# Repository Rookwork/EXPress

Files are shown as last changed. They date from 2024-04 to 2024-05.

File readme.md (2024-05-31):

# EXPress

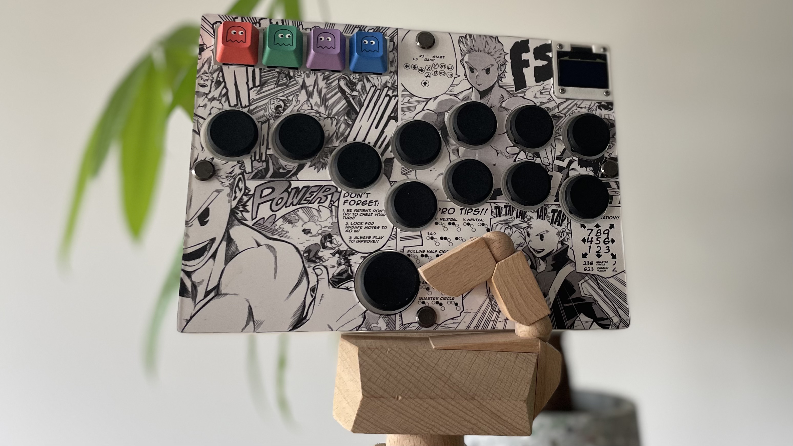
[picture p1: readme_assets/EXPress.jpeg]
The EXPress Controller


The EXPress (pronounced ee-ex-press, like EX moves) is a leverless DIY arcade controller with a focus on self expression.

**Features**
- Space for custom art on both the front and back
- Extra keys use MX switches with a slightly wider spacing to accommodate thicker artisan keycaps
- Main keys use Choc switches for faster inputs
- All switches are fully hot swappable
- Runs open-source GP2040-CE firmware for extremely low latency and fully remappable buttons 
- Includes an OLED screen to display layout and current mode

Custom art

Please note that I am providing these files free of charge with no promise of warranty or support. I try to explain the assembly process thoroughly, but it does still require some basic soldering skills and it is possible to mess up. Please take things slow, be careful, and try to enjoy the act of making something. :) 

I suggest reading through the entire guide at least once before deciding to order anything to make sure you understand each step and have the necessary tools. 

## Assembly guide

To assemble an EXPress, first we will need to order some parts. I will show the process using the exact vendors and process that I used, but there are many alternatives if you would like to shop around. The total cost of an EXPress should be around $150, give or take depending on how you get the parts made. 

Throughout this guide you will see expandable sections like this: 
<details>
<summary>"Click me to read more"</summary>
More information!
</details>

This guide is long, so various steps are hidden for readability. If you would like more detailed explanations of each step, just click the arrow to expand it and there will be more text and pictures.

### Ordering parts

We will need to order a few off the shelf parts:
- MCU: [Waveshare RP2040-Zero](RP2040-Zero) | [Amazon link](https://www.amazon.com/RP2040-Zero-High-Performance-Microcontroller-Castellated-Applications/dp/B09KZPCNPL)
- OLED Screen: [SSD1306 128x64px OLED Display](https://hosyond.com/#:~:text=0.96%20inch%20IIC%20OLED%20Module) | [Amazon link](https://www.amazon.com/gp/product/B09T6SJBV5/) | Note that there are lots of similar displays, but I can't guarantee they will fit. Many of these displays have similar measurements, but the tolerances are tight for this part, so I would try to get this exact screen if possible just to be on the safe side.
- 12 Choc v1 switches (whichever kind you want). I suggest a linear switch like Choc Reds, or an even lighter option like Pro Reds or Purpz. 
- 4 MX switches (whichever kind you want, but a 5-pin, PCB mount switch will be slightly more secure). Don't be afraid to try a fun switch you might not otherwise use — You don't hit these keys that often. I used Kailh Box White switches, for example. 
- 12 Choc v1 circular keycaps. I used ones from Junkfood Arcades, but you can also 3D print some, like those from [jfedor](https://github.com/jfedor2/flatbox/tree/master/3d-printed-buttoncaps) whose Flatbox design was a great inspiration to me. 
- 4 MX keycaps (whichever kind you want)
- 4 M5 15mm long Chicago screws | [Amazon link](https://www.amazon.com/gp/product/B09TT3TNPP) (set of several lengths)
- 10-16 M2 screws, 6-8mm long, and nuts | [Amazon link](https://www.amazon.com/gp/product/B0BD2CXW7D) (set of several lengths)

We will also need to get the following parts made:
- Three PCBs: the main body Choc switches mount, the MCU (microcontroller) mount, and the MX switches mount. These are three separate PCBs due to the different heights of these various parts. 
- The body of the case. We'll get this 3D printed. If you have your own 3D printer, you can probably make this yourself and save quite a bit of money.
- The top and bottom plates. We'll get these laser cut from acrylic. 
- Your own custom art

#### Ordering PCBs
<details>
<summary>"Ordering PCBs from JLPCB"</summary>
I used JLPCB for this. Upload each of the PCB zip files (one at a time). The only option you **must** change is the PCB thickness. This should be set to 1mm for each PCB. Do not forget!

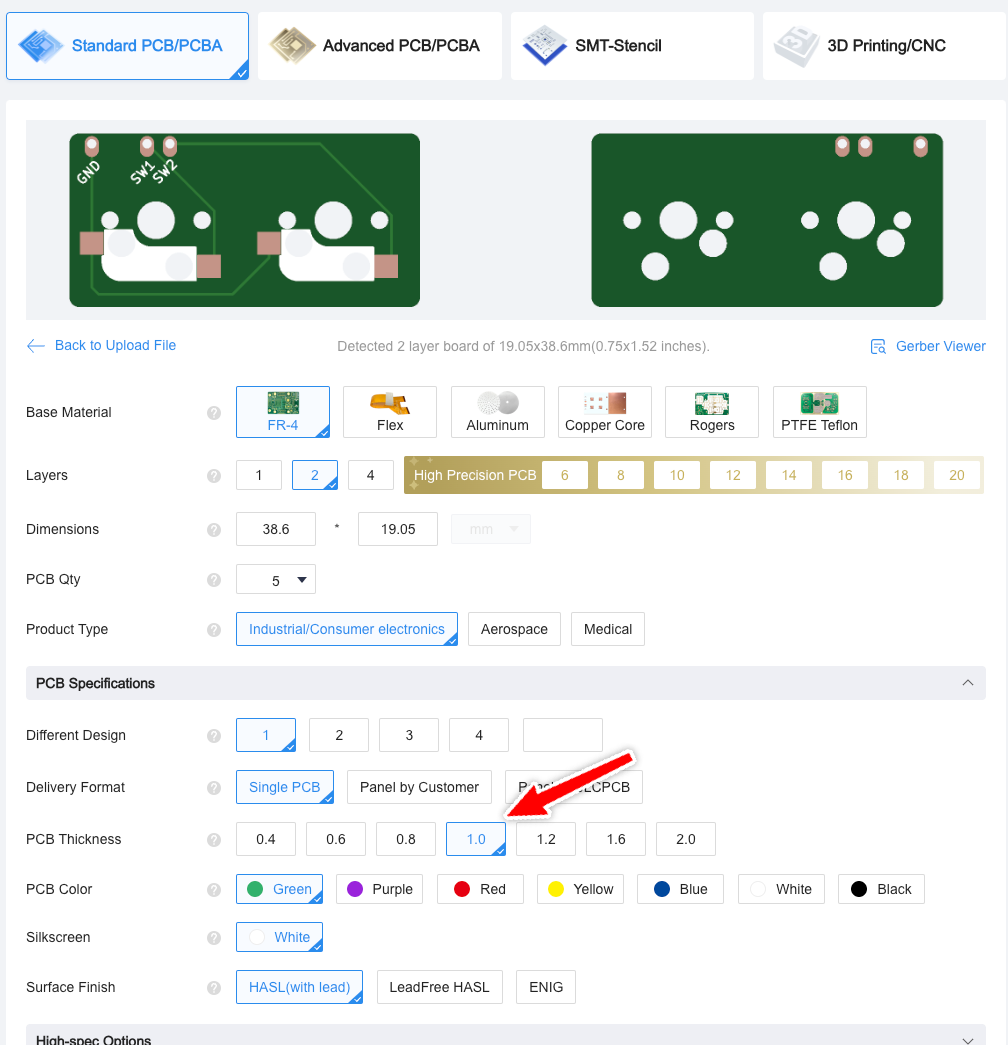
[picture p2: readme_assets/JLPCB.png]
PCB ordering


You can also change the color if you want, but these will be covered by art, so it's not really necessary.
</details>

#### Ordering body
<details>
<summary>"Ordering body from Shapeways"</summary>
I used Shapeways for this. Upload the body .stl file and double check the dimensions. It should be 199mm x 145mm. Then choose your material. I recommend SLA12, the cheapest option.

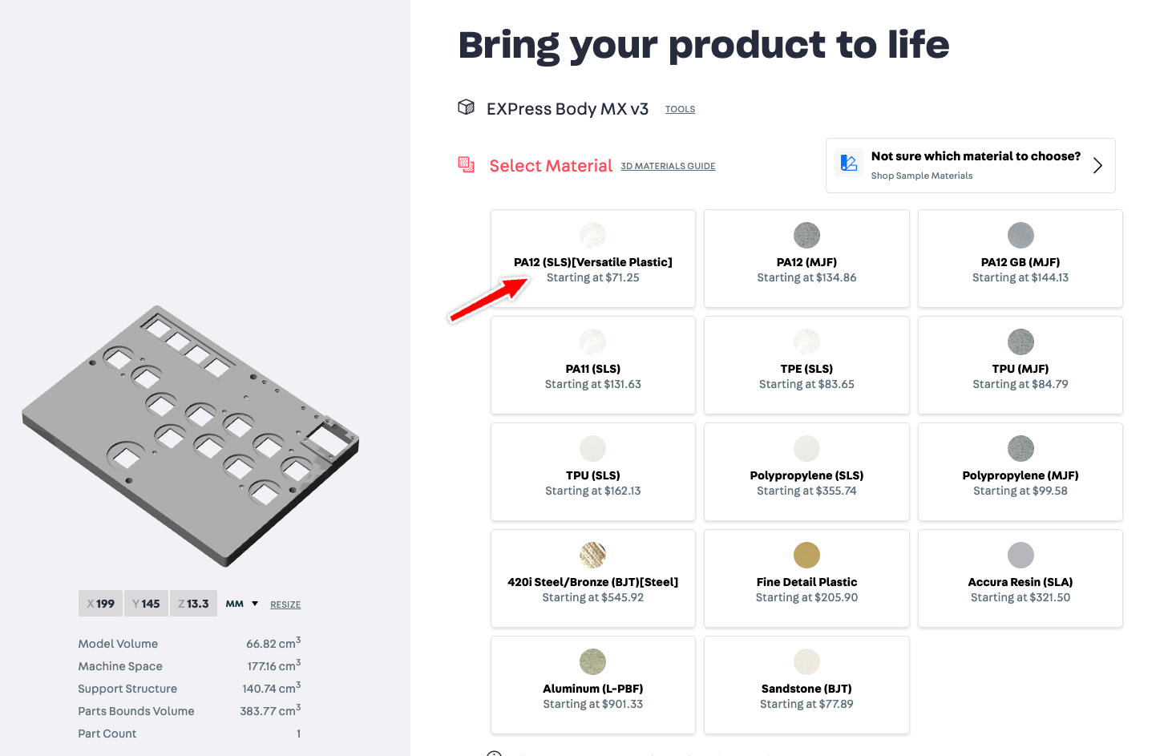
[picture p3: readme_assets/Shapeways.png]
Material


You can also change the color and finishing, but I have always used the default finishing option and have never had a complaint. The texture of the print will only be on the side of the case, you won't feel it, so it's not that important for it to be smooth.

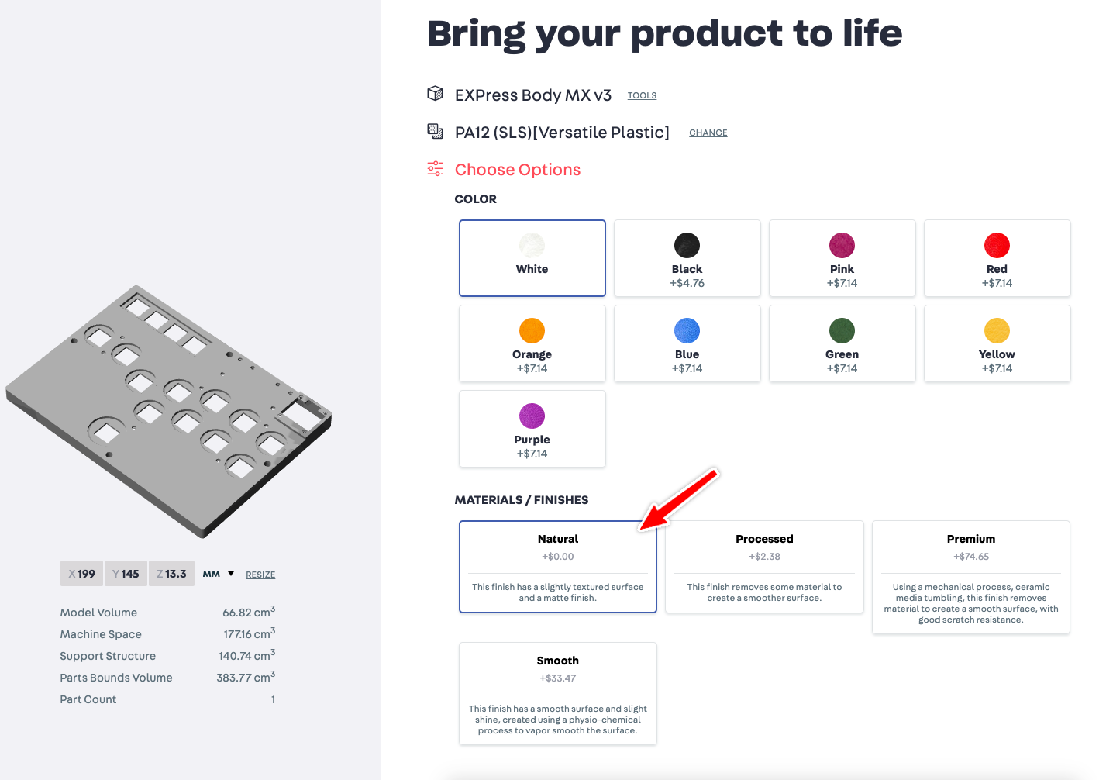
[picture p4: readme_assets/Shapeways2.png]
Color and finish

</details>

#### Ordering plates
<details>
<summary>"Ordering plates from Ponoko"</summary>
I used Ponoko for this. Upload the art plates .svg file. You may need to change the dimensions. 

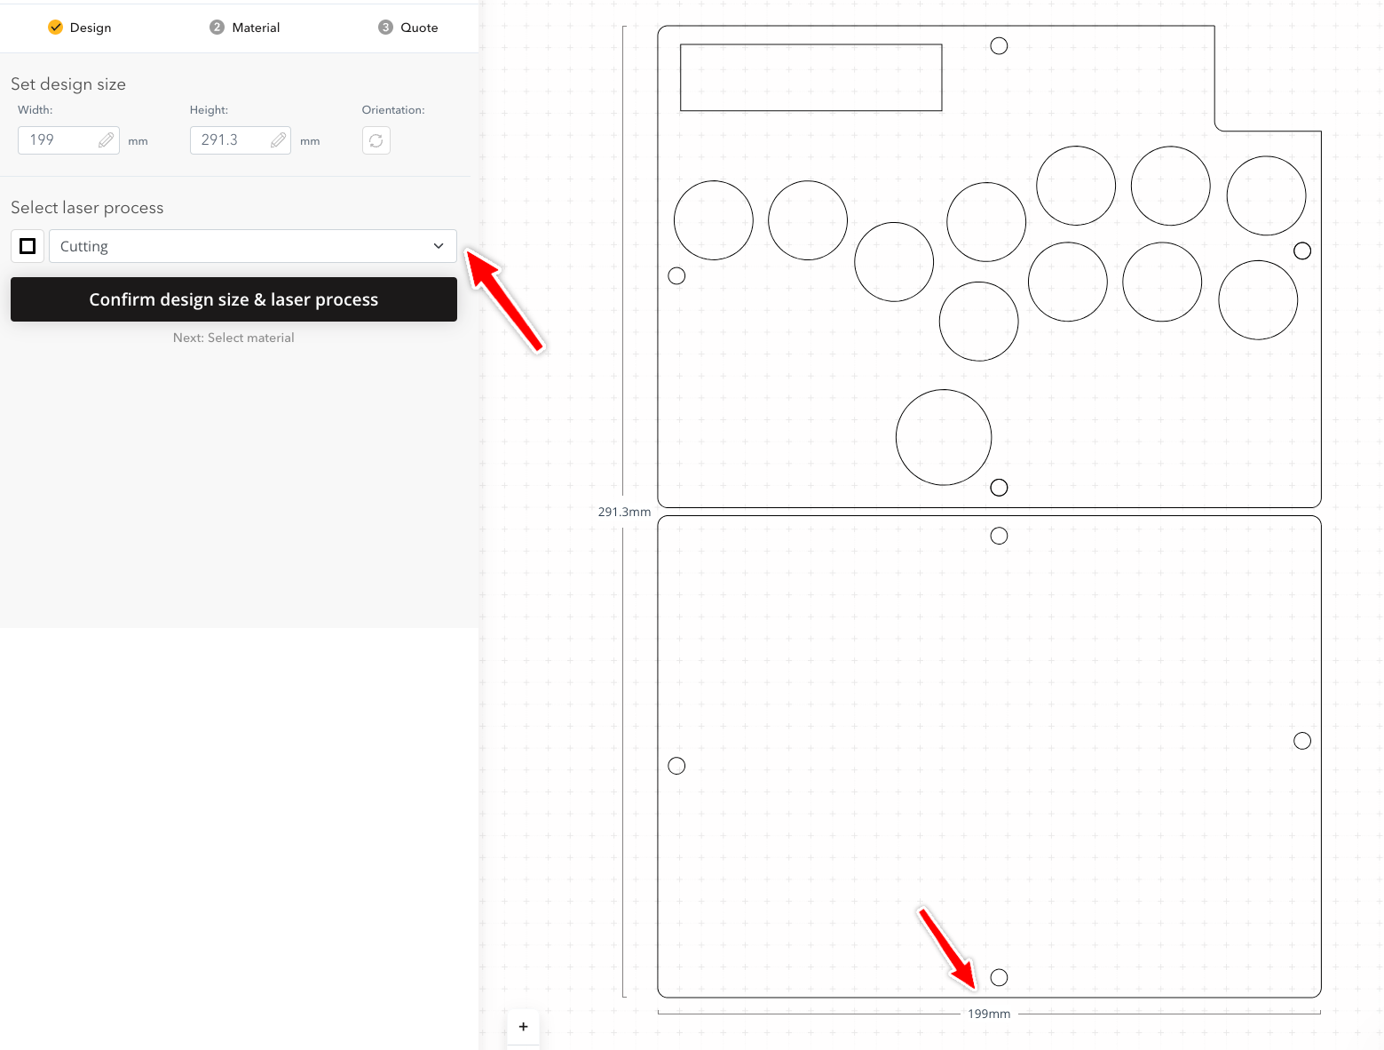
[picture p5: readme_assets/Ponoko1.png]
Ordering through Ponoko


Double-check that the width is 199mm specifically. Also, make sure the lines are set to "Cutting". 

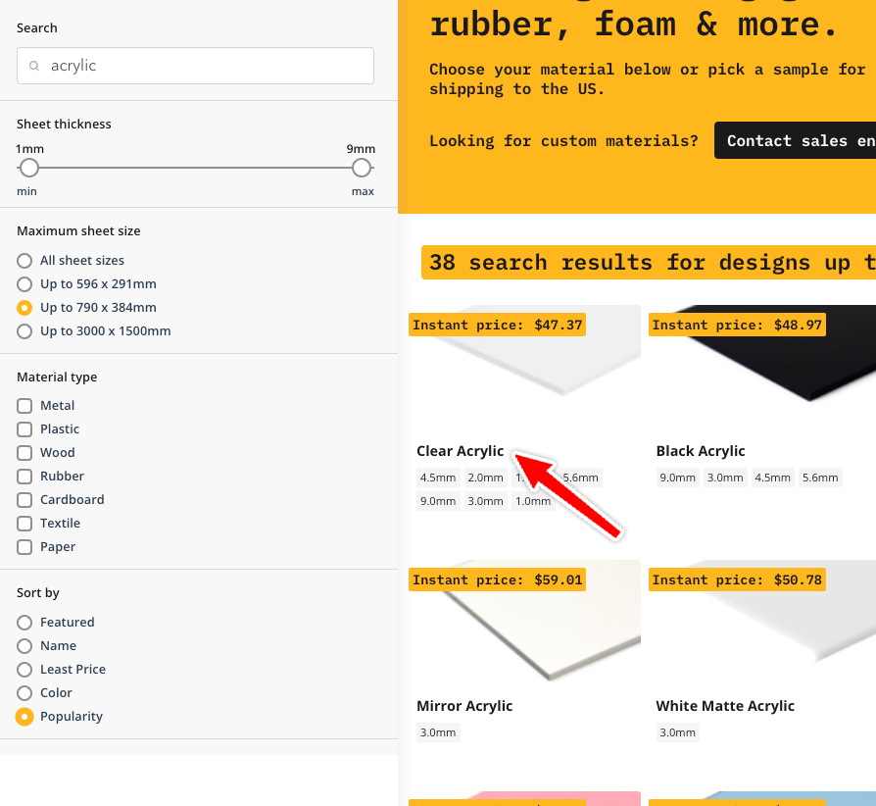
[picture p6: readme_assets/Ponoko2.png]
Ordering through Ponoko


Then, select your material. We want plain old clear acrylic. 

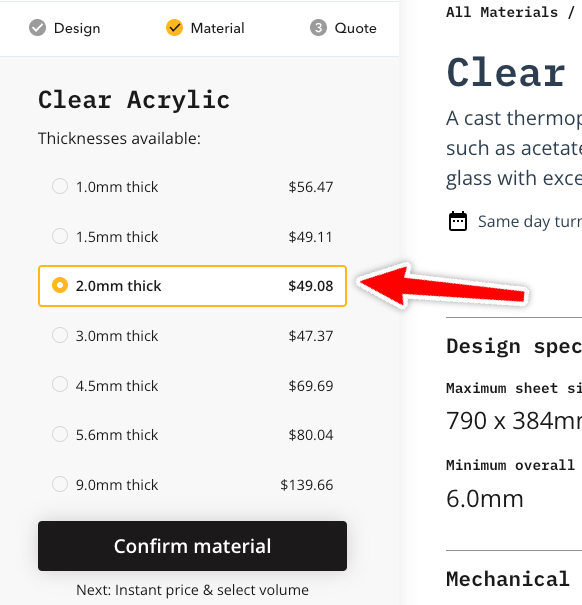
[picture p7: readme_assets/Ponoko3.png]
Ordering through Ponoko


Thenk select the thickness. **This is important.** Choose 2mm. 

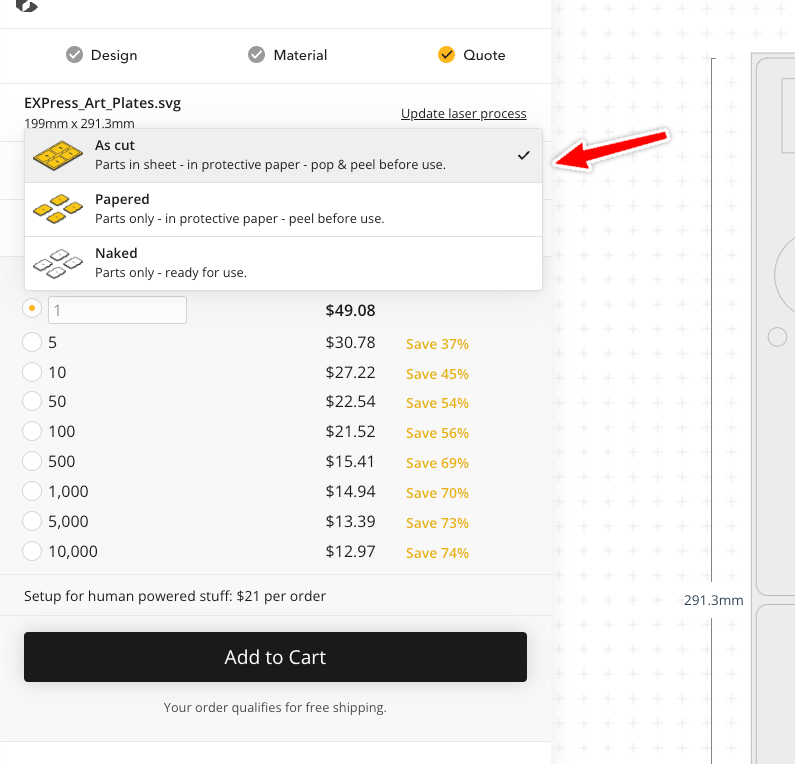
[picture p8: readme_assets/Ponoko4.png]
Ordering through Ponoko

You can also choose how you want the parts delivered. I like to leave it on "As cut". That means you'll get a big sheet in the mail and you pop the pieces out yourself. You can also choose "Papered" if you want a smaller package. I would not choose "Naked". It is far more expensive and not ideal for our purposes. We want the acrylic protected by the paper until we're ready to install it to avoid unnecessary smudges and scratches. 
</details>

#### Ordering custom art
<details>
<summary>"Ordering custom art through FedEx Office"</summary>
The art plates are designed to be printed on an A4 sheet of paper, but this is fairly hard to find in the US, so printing on an 11"x17" sheet with more whitespace around the design is also an option.

You can use the same .svg to help lay out your design. Note that the back plate screw holes are offset purposely — don't change them. This is necessary for the art to print correctly. 

I just used FedEx Kinko's copy service. If ordering online, choose "Copies" and a thicker paper for durability. 60lbs or 80lbs are both fine. Also, make sure you choose 11x17.

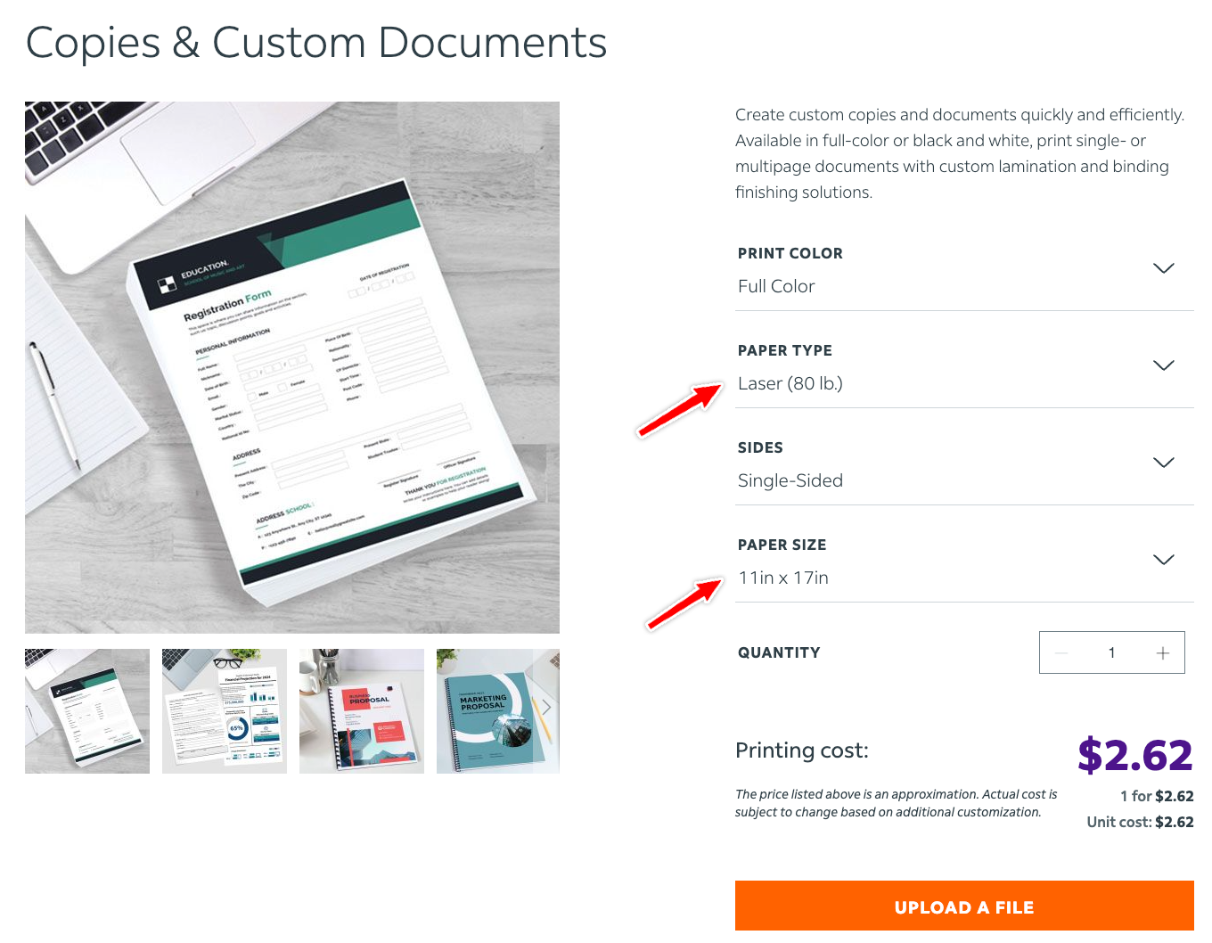
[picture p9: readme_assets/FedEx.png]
Ordering art


If you upload your file and FedEx asks you to resize it, stop, something is wrong. You should upload a file that is exactly 11x17 and FedEx shouldn't have any feedback about it. Resizing art through FedEx's tool makes this far more complicated. 

You could also check if a local print shop would do the job, but their willingness to do this will vary. This is an extremely small job for most shops, so it may not be worth the time to set it up. 
</details>

### Soldering and assembly

Before you begin soldering, there are a few other supplies you'll need
- Soldering iron and solder
- Some small gauge wire. I like 28 or 30 AWG. 

By the time you're reading this, I may have made some minor changes to the design of the PCBs, but the idea behind this process will be the same. If there are any major changes, I will note them. 

The overall idea here is we will complete the individual PCBS, put them in place, then connect them together. 

#### Test the MCU
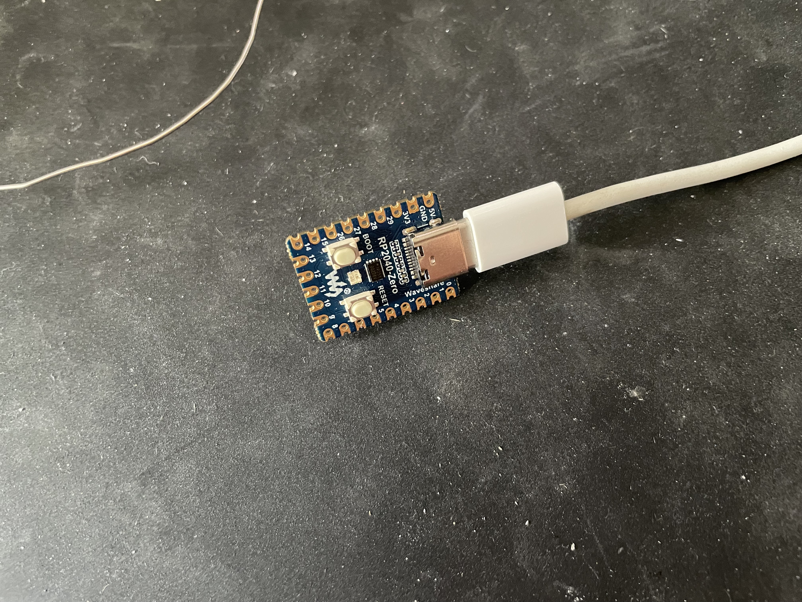
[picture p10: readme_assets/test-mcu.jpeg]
Test the MCU


<details>
<summary>"Testing the MCU"</summary>
Before you start anything else, it's a good idea to make sure your RP2040-Zero can flash the firmware. To do this, hold down the Boot button while plugging the board in. You should see it show up like a USB drive. Drag the firmware file into it and wait for it to disconnect. 

If you want to test the contacts of the MCU itself, you can bridge the ground pin to other contacts. You'll see buttons pressed on a tester like this: [https://hardwaretester.com/gamepad](https://hardwaretester.com/gamepad). You don't have to do this at this stage, though. As long as you can flash, things are probably on track.
</details>

#### OLED screen

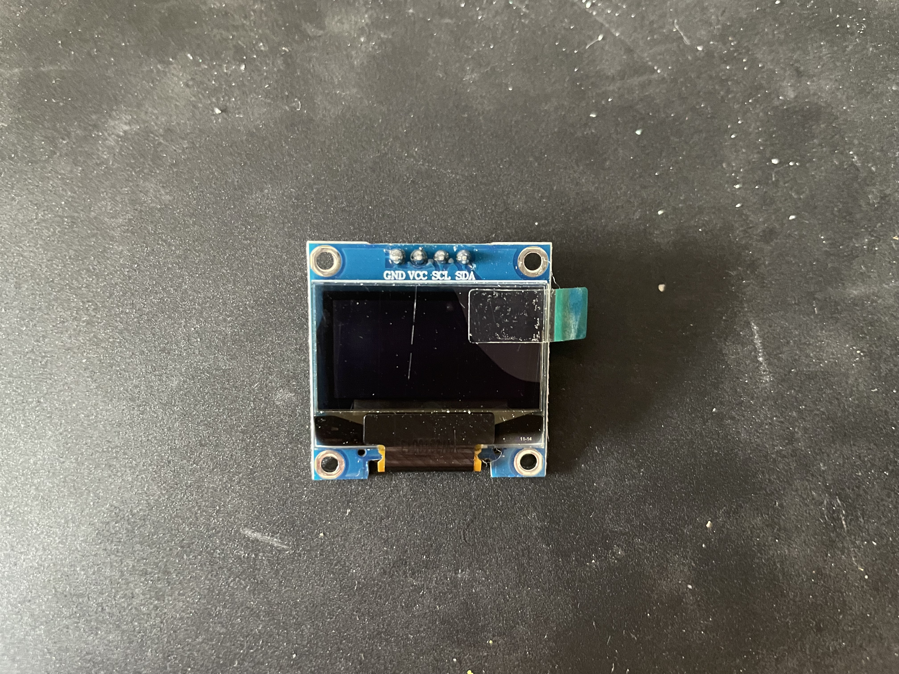
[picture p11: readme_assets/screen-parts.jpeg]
OLED screen


<details>
<summary>"Prepping the OLED screen"</summary>
There's not much we need to do with the screen besides trimming the existing pins if they come pre-soldered. You can leave the underside pins if you want, but you much trim the top pins down so the screen will fit flush. 

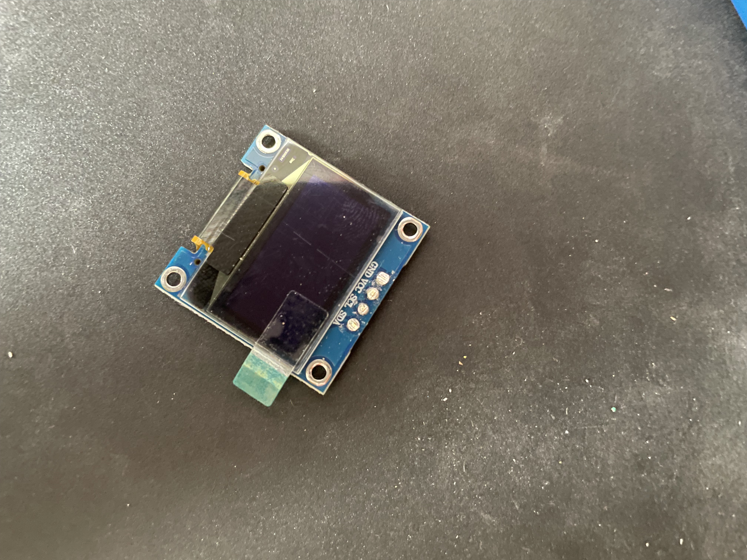
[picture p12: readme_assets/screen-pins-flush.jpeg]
Screen pins trimmed


Also, note the order of the pins and tin them.
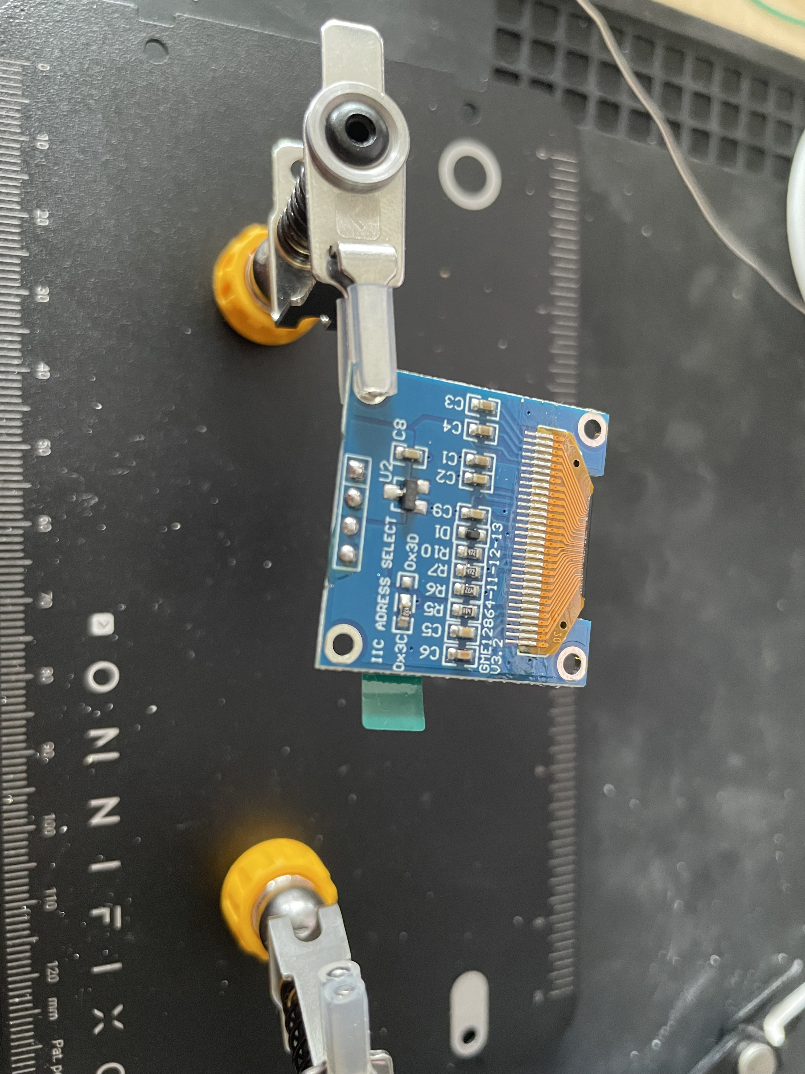
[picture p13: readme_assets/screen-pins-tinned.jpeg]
Screen pins tinned
 
</details>

#### MCU mount PCB

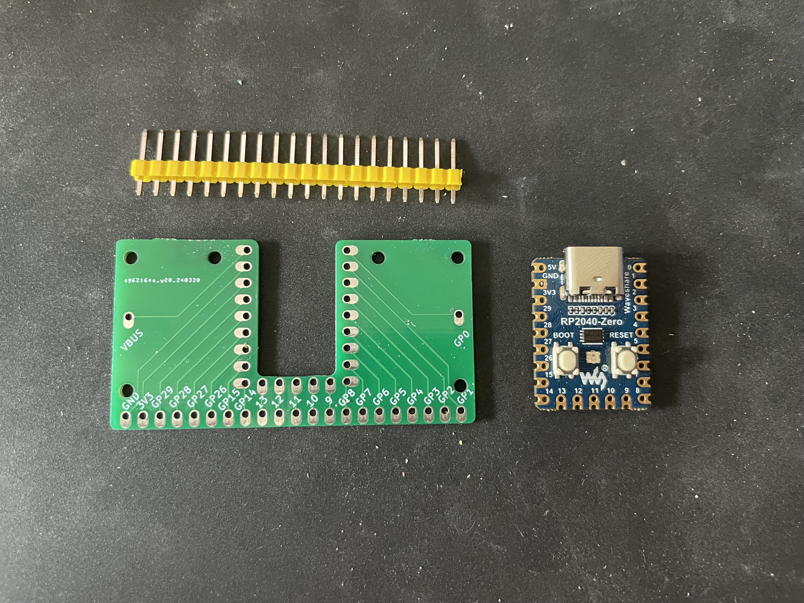
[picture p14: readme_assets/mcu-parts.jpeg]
MCU mount parts


<details>
<summary>"Preparing the MCU (microcontroller) mount"</summary>
To mount the RP2040-Zero, we need to attach it to the mounting PCB first. This will also make connecting the boards together a little more straightforward. 

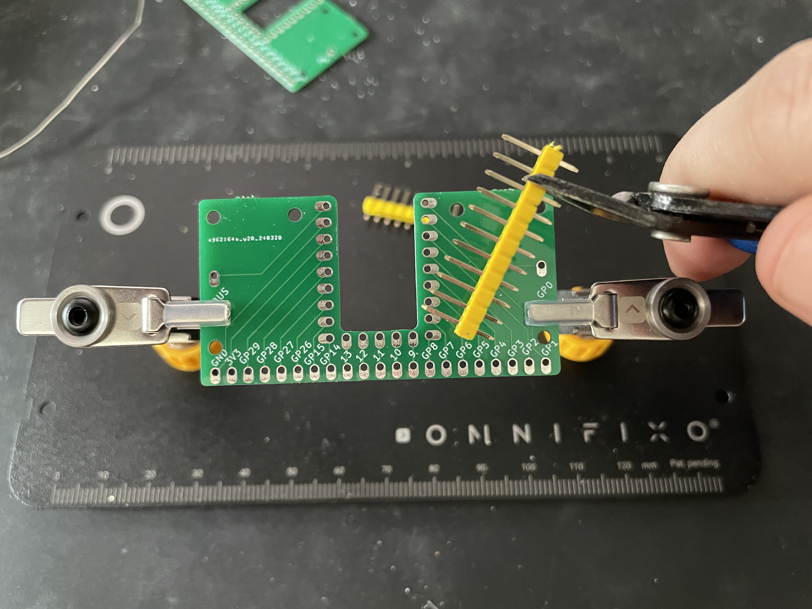
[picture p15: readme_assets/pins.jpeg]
Pins


There are a variety of ways you can mount the MCU. I recommend using a line of pins like this (it's okay if the line has too many pins — you can cut it to the right number), taping it to the back of the mount, and soldering the corners first so it stays in place. 

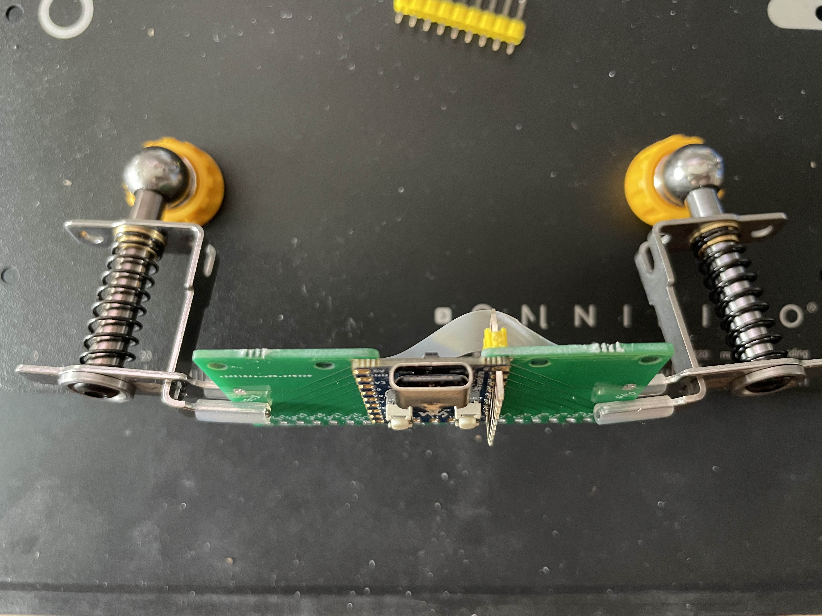
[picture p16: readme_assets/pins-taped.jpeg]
Pins taped on


It doesn't have to neat because we'll be trimming this in a moment. Finish soldering the line of pins. 

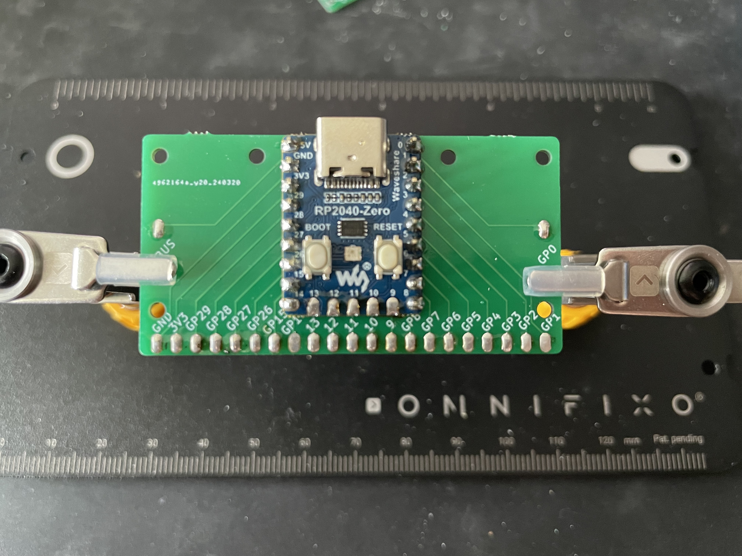
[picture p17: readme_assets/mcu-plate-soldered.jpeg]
MCU plate soldered


Then, work some snippers underneath the rubber sheathing and snip. Do this for all the pins so they are more or less flush (a little excess is okay.)

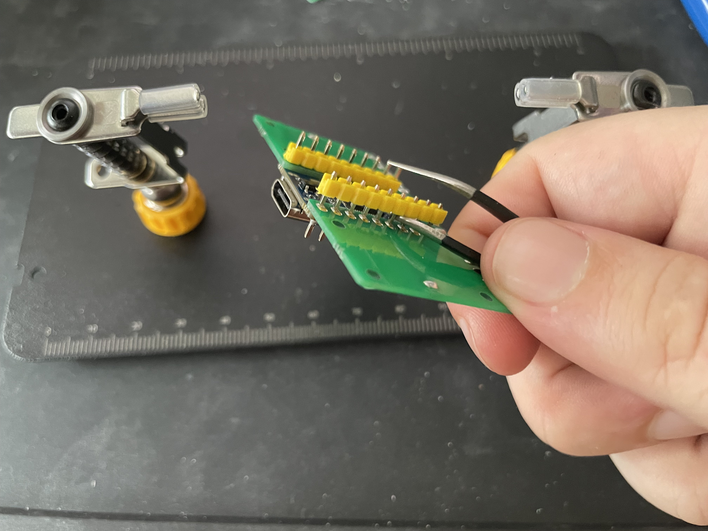
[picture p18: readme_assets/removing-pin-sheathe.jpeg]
Removing the sheathe from pins


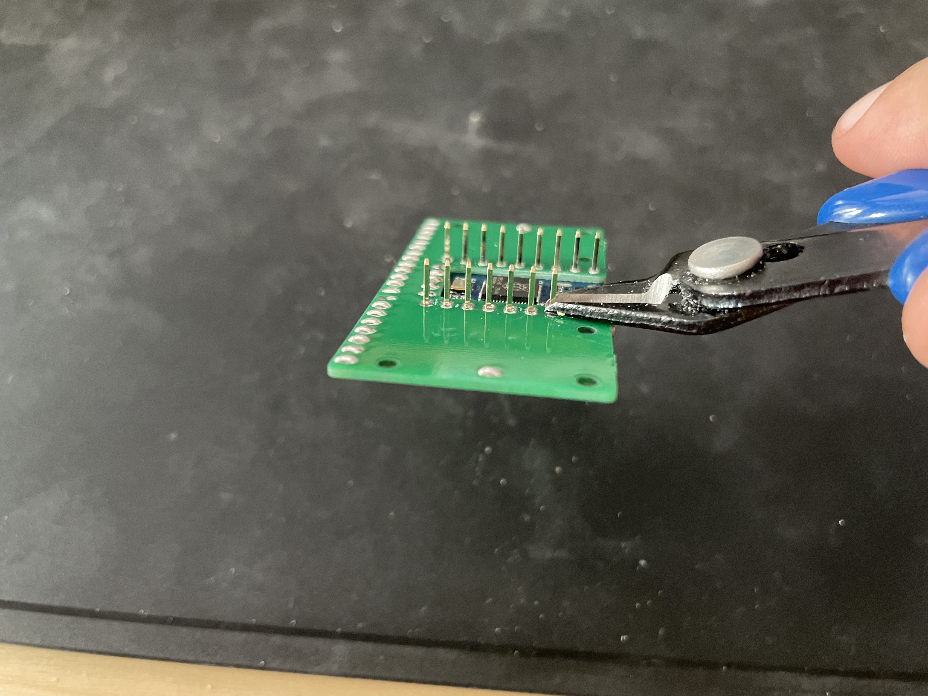
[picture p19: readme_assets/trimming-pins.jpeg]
Trimming the pins


Once the MCU is soldered on, it's also a good time to tin the other contacts with little mounds of solder on each one. 

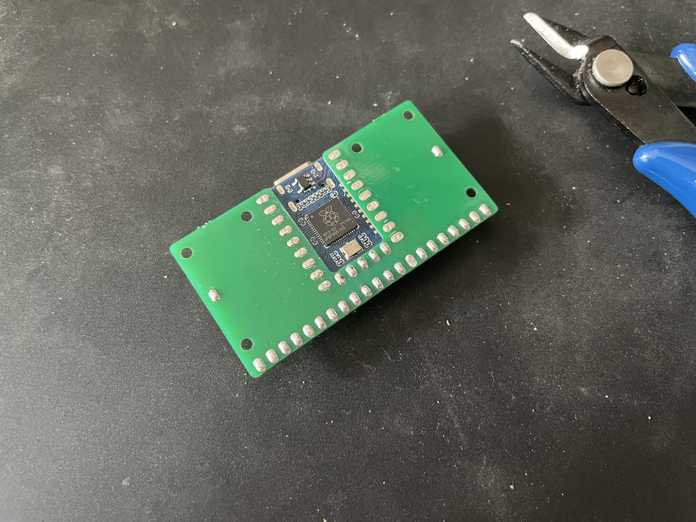
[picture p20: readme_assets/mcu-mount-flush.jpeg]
MCU mount trimmed flush

</details>

#### MX switch PCBs

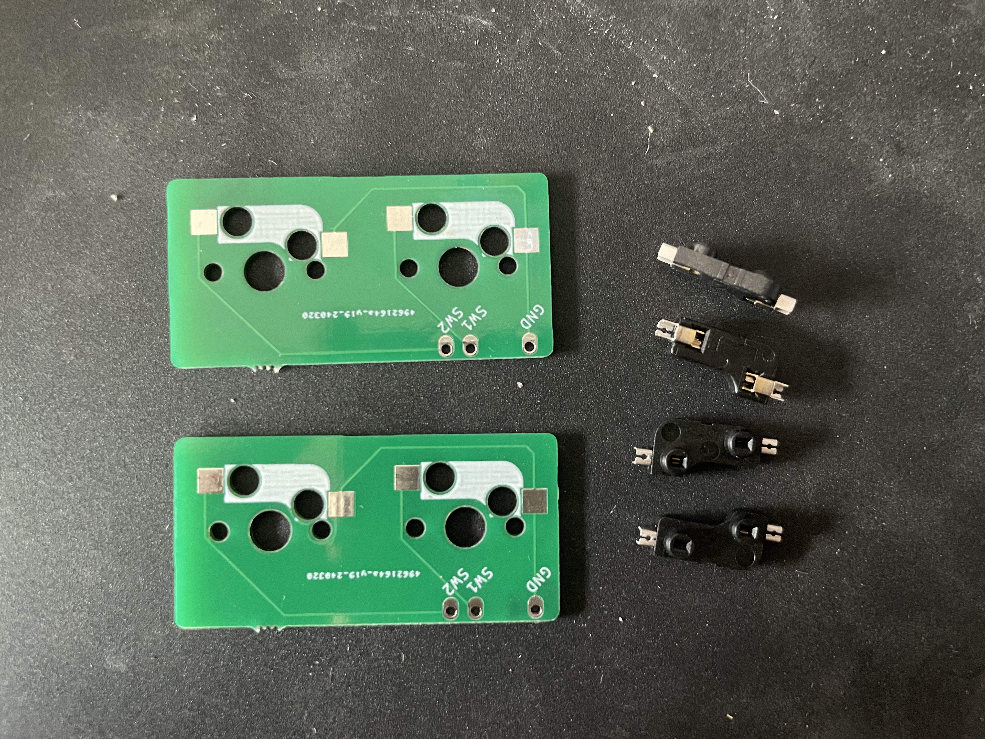
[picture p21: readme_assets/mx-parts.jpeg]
Preparing MX parts


<details>
<summary>"Preparing MX switch PCBs"</summary>
The MX plates are very straightforward. We just need to solder the hotswap sockets and tin the contacts. 

To solder the hotswap sockets, just hold the socket down and add solder to one side. Continue holding it for a second while the solder hardens to make sure it's flush. 
 
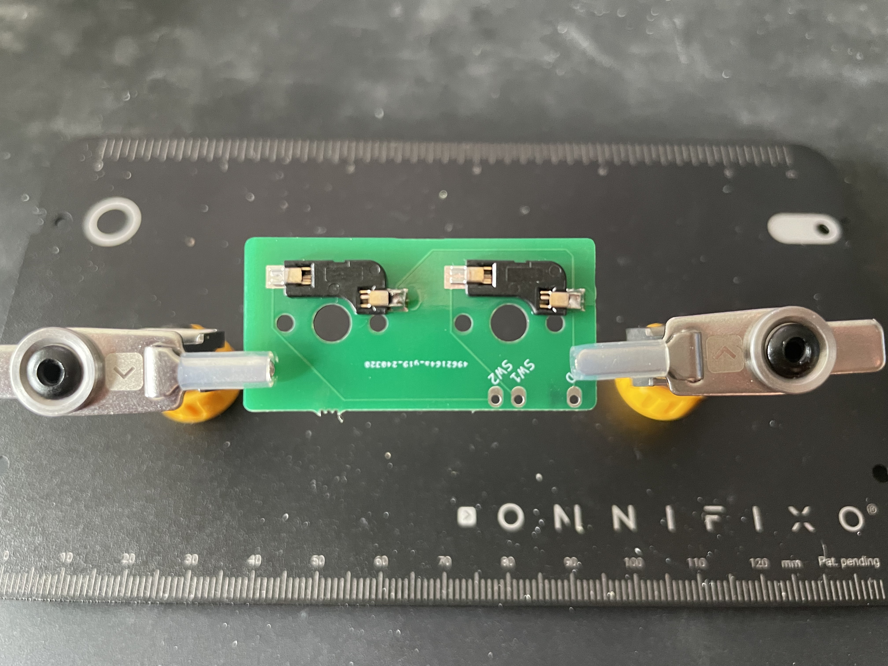
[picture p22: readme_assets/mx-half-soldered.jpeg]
One half of MX switch soldered


Then solder the other side and tin the contacts. 

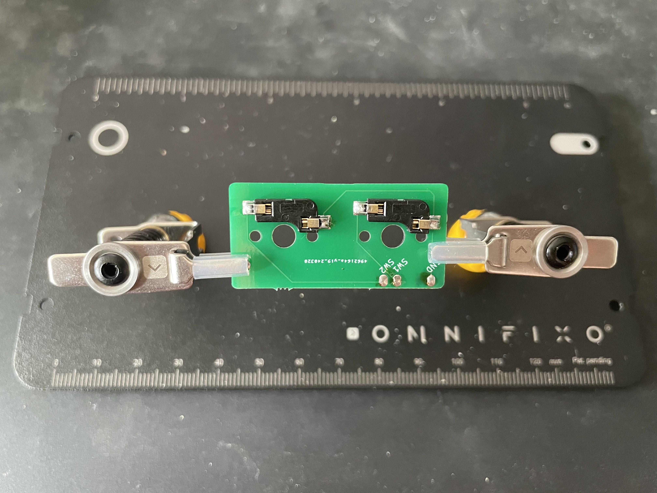
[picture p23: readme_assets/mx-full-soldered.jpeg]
MX switch mount soldered

</details>

#### Choc switch PCB

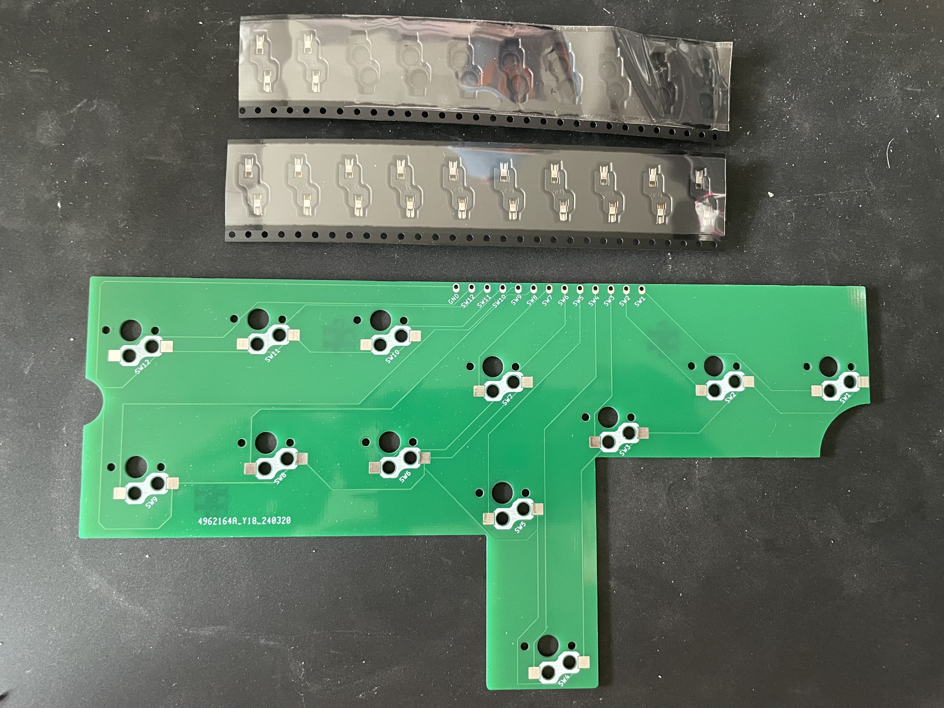
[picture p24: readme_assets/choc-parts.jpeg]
Choc switch parts


<details>
<summary>"Preparing the Choc switch PCB"</summary>
The Choc PCB is exactly the same as the MX ones. There are just more switches to solder. 

**Note the current Choc PCB is different from the one pictured. The process is still the same.**

Solder one side, then solder the other and repeat. Also, tin the contacts.

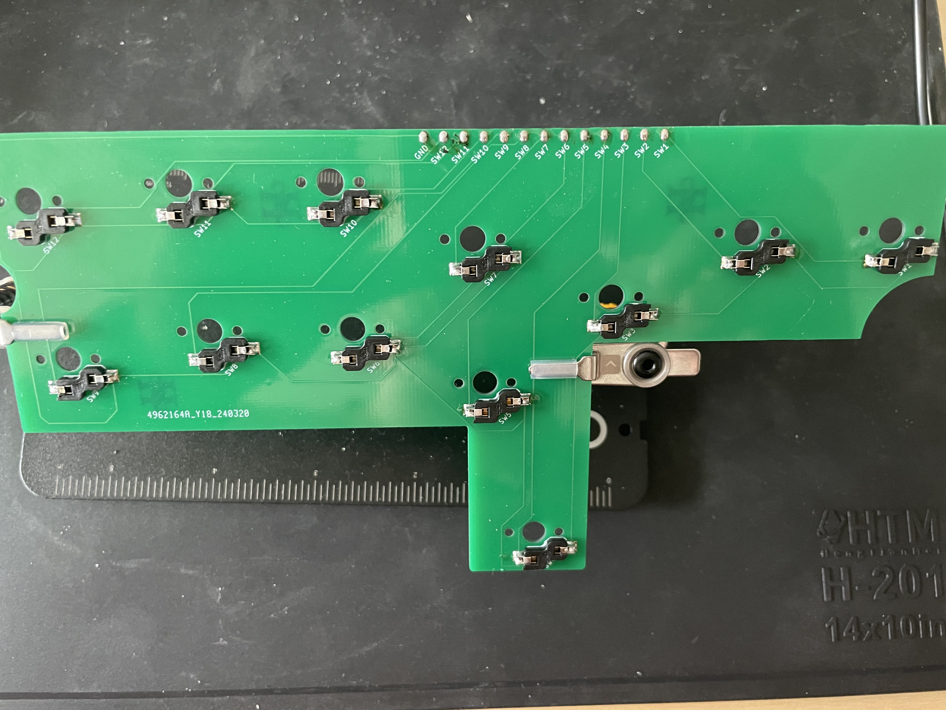
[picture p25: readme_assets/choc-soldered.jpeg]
Choc switches soldered


And tin the contacts above.
</details>

#### Installing the PCBs

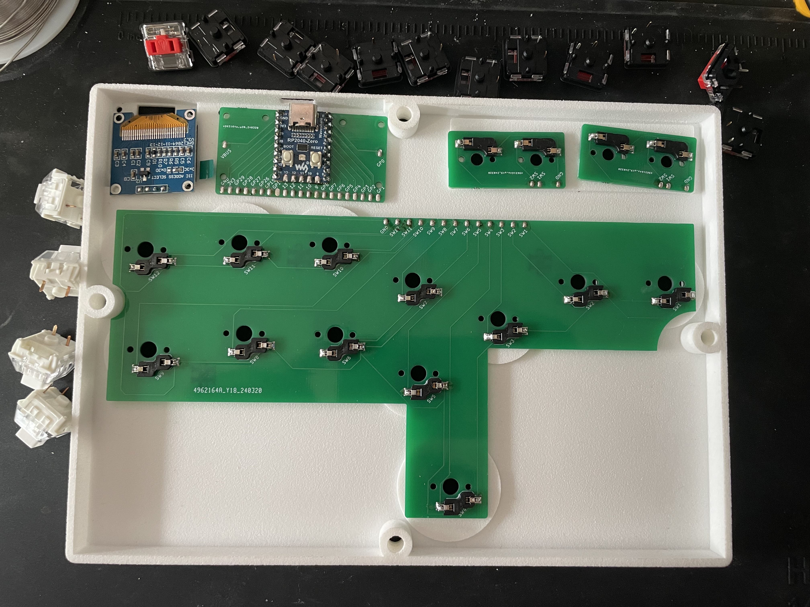
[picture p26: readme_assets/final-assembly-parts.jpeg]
Parts for final assembly


<details>
<summary>"Installing the PCBs in the body"</summary>
The OLED screen and the MCU mount will be held in with M2 screws. The MX and Choc PCBs are secure enough just from clipping the switches into them, but the Choc PCB includes optional M2 screw holes as well. You won't see them in the images below, but they are included in the latest versions of the body and PCB. 

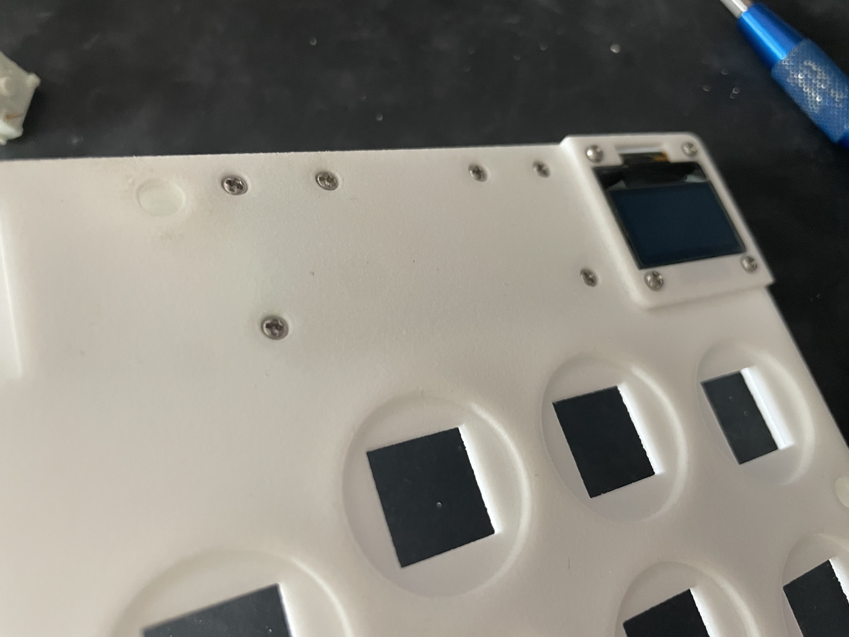
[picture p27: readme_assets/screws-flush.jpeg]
Screws flush


Screw in the OLED screen and MCU mount. The MCU screws are meant to sit flush in the body to be covered by the art. The OLED screw holes are a little tricky. Try to hold the nuts in place with tweezers and screw from the top. 

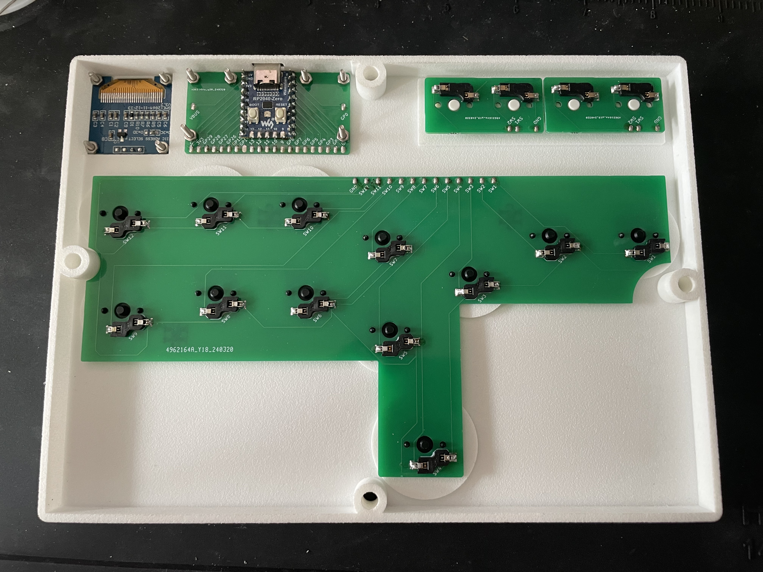
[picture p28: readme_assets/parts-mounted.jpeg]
All parts mounted


To install the switch mounts, clip the corner switches into the case first, then clip the PCBs onto the switches. When installing switches, **make sure to support the hotswap sockets from the back**. If you don't support the sockets, they may snap off. This is fixable, but it's annoying. 
</details>

#### Connecting them all together

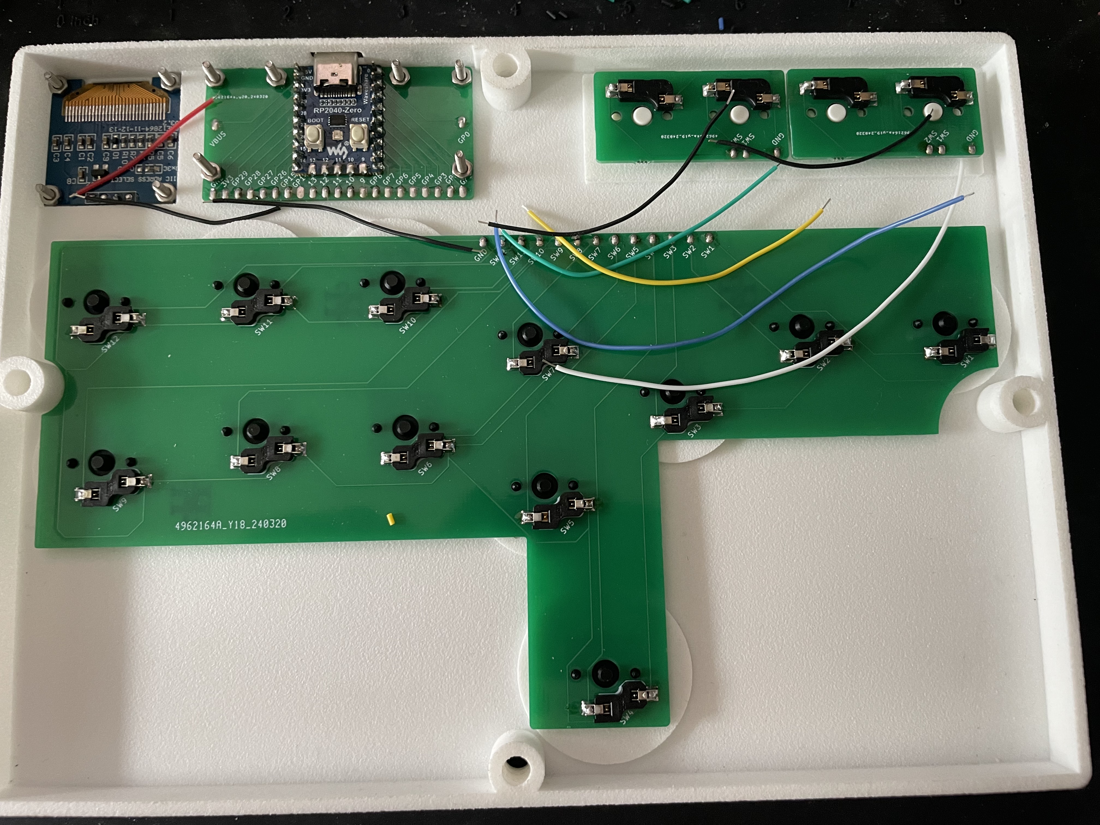
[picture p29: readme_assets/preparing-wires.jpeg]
Preparing the wiring


<details>
<summary>"PCB wiring guide"</summary>
Once everything is in position, it's time to break out the wire. Everything is in order. 

| Hardware pin | Switch # | GP2040 Button | Xbox Button |
| --- | --- | --- | --- |
| GP29 | - | - | - |
| GP28 | - | - | - |
| GP27 | - | OLED SCL | - |
| GP26 | - | OLED SDA | - |
| GP15 | 12 | L2 | LT |
| GP14 | 11 | L1 | LB |
| GP13 | 10 | R2 | RT |
| GP12 | 09 | R1 | RB |
| GP11 | 08 | B2 | B |
| GP10 | 07 | B4 | Y |
| GP09 | 06 | B1 | A |
| GP08 | 05 | B3 | X |
| GP07 | 04 | DPAD_Up | Up |
| GP06 | 03 | DPAD_Right | Right |
| GP05 | 02 | DPAD_Down | Down |
| GP04 | 01 | DPAD_Left | Left |
| GP03 | L_01 | L3 | LS |
| GP02 | R_02 | R3 | RS |
| GP01 | L_01 | S1 | Back |
| GP00 | L_02 | S2 | Start |

Simply heat up one contact, insert one end of the wire, and hold for a second. Then, repeat on the other side. 

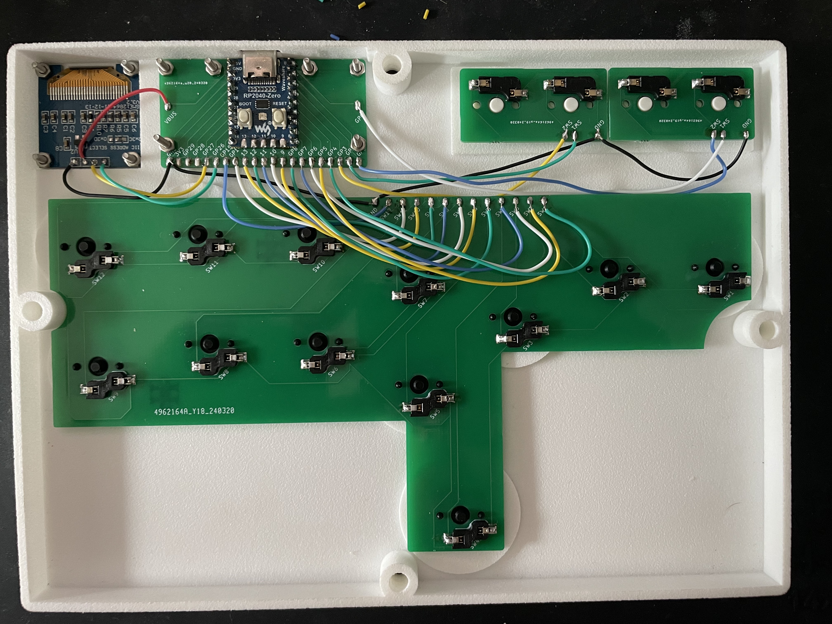
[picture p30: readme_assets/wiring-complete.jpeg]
Wiring complete

</details>

### Adding custom art
Please see [Cutting a Circle for Arcade Buttons](/cutting_arcade_stick_art/readme.md).

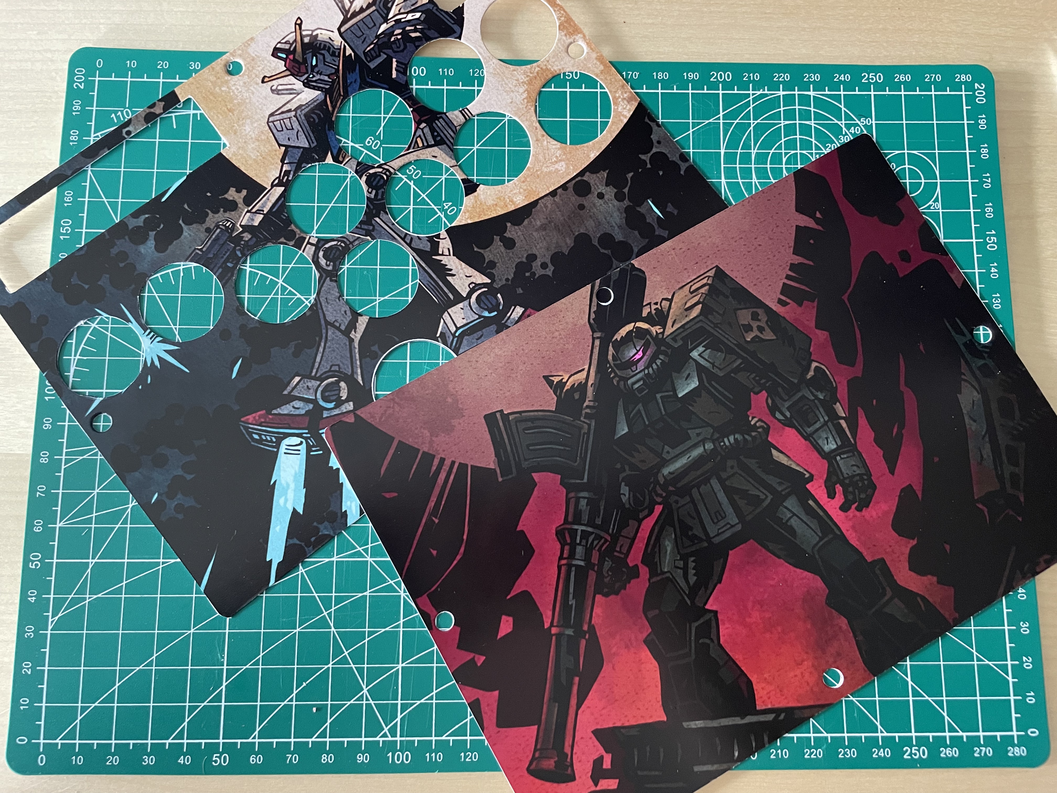
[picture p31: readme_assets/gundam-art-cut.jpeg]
Artwork cut out


The manga panels used for one set of art panels are from Boku No Hero Academia by Kōhei Horikoshi.
The Gundam art used for the other set of art panels are from [Chris Bourassa](https://twitter.com/bourassaart?lang=en). 

I made these art files for my personal use and will not be distributing them. 

### Flashing the firmware
If you flashed the firmware for testing earlier, the controller should now be working. If not, flash it now. 

To change any of the settings or pin mappings, you can use the great GP2040-CE web configurator: [https://gp2040-ce.info/web-configurator/](https://gp2040-ce.info/web-configurator/)

### Final assembly
With everything working, all that's left to do is remove the paper from the acrylic plates, put the art down, put the plates down, and screw everything together. While you do this, try to be careful not to touch the underside of the acrylic (the side that will touch the art). That way, any smudges that develop will be on the top faces and easy to clean. 

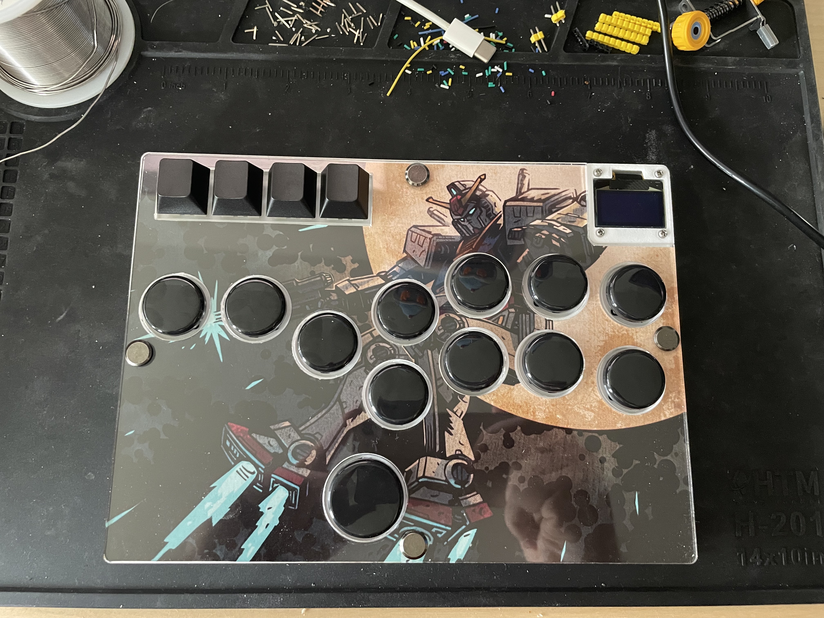
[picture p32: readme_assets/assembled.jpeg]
Two assembled EXPress controllers


Enjoy your EXPress! 

---

If you found this guide helpful, tips are always appreciated but never required.

<a href="https://www.buymeacoffee.com/rookwork" target="_blank">Buy Me A Coffee</a>

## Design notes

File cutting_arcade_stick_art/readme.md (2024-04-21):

# Cutting Custom Arcade Stick Art

When I first started working on [the EXPress](/readme.md), I had lots of worries about parts that would be difficult. Little did I know that one of the most difficult parts of this project would be something that never even occured to me to worry about: cutting circles. 

With traditional arcade buttons, you have little lips that cover any rough cuts, but with Choc switches, you don't have that luxury. Your cuts will be on full display, so they need to look good. 

I tested several methods and finally landed on one that produced good results. Here, I'll share my findings and tips. Not to spoil the surprise too much, but I only really recommend methods 1 and 4. 

## Method 1: Freehand with a standard hobby knife

You will want a hobby knife for this project anyway, so this is the cheaper approach with what you already have on hand. The results won't be as pretty, but if you're patient, you can still get decent looking cuts, especially at a distance. 

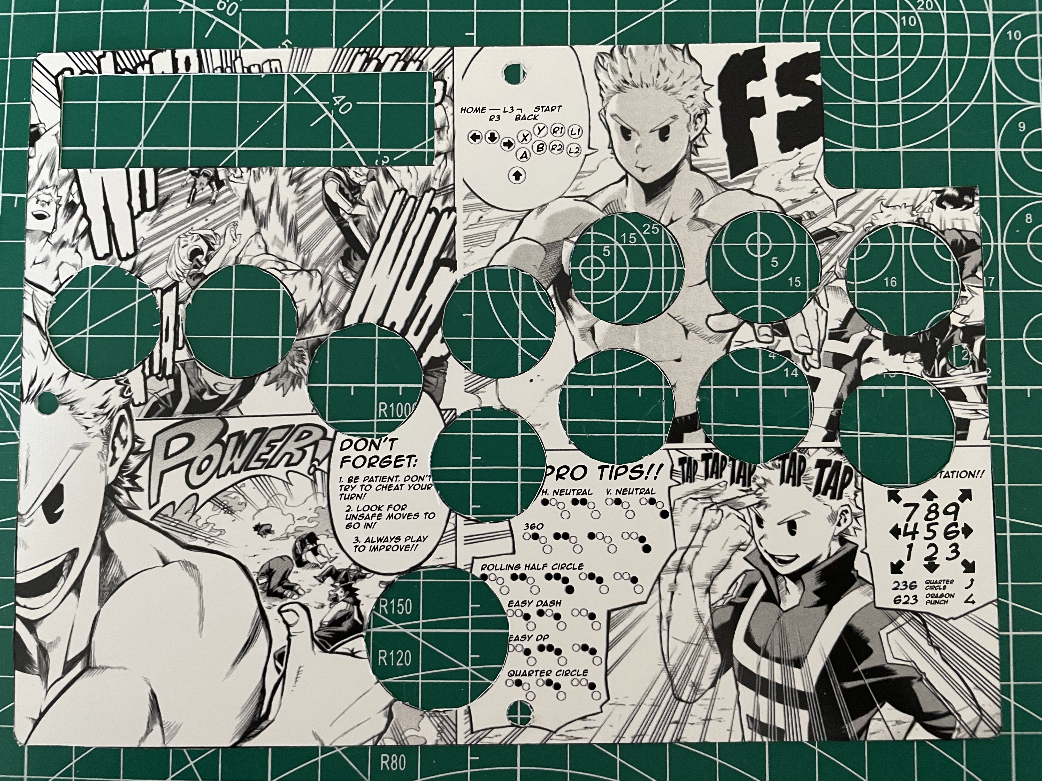
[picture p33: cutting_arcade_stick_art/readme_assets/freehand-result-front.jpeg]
Front

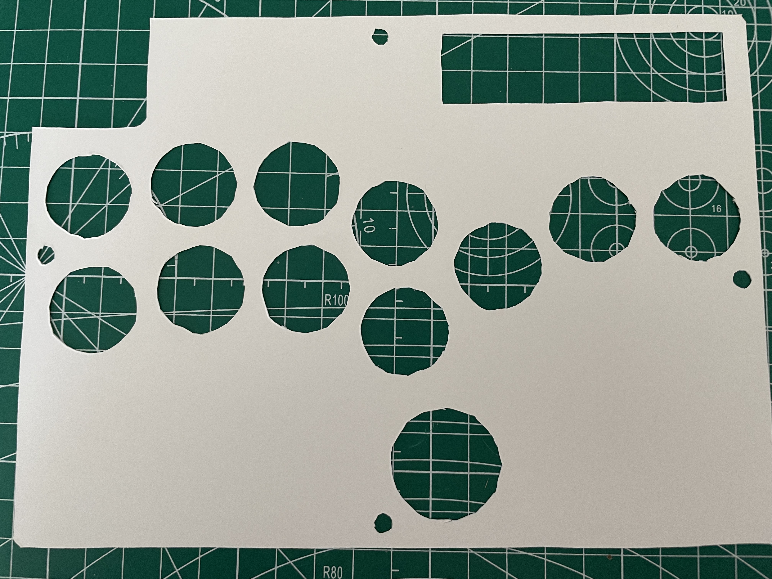
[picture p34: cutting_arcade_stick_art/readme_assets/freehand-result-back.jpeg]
Back


It's not perfect, but the manga panels here mask the messiness a bit, so the style of art you choose can also matter. Some tips on this method: 

### Go very, very slow
By the time I was done with this one, my hand was in a lot of pain. I was cutting so slowly and carefully that the knife was pressing into my hand for a long time. I suggest doing half and coming back after a break. It's exciting to cut the art, but coming at it fresh helps you get better results. 

When cutting the circles, think about lots and lots of small straight cuts that create the sort of illusion of a circle. From a distance, this can work. 

### Use a new blade
This almost doesn't need to be said, but you want your blade to be as sharp as possible for this. I broke a blade near the end of cutting this one. You might want 2-3 blades on hand just in case. 

### Cover the art as you cut
If you have sweaty hands like me, there is a big risk of getting finger oils on the art as you work. Using anything really (cardboard works well) between your hands and the art helps a lot. Try to minimize the amount of skin contact you make with the art — that goes for any of these methods. 

## Method 2: A special circle cutting tool

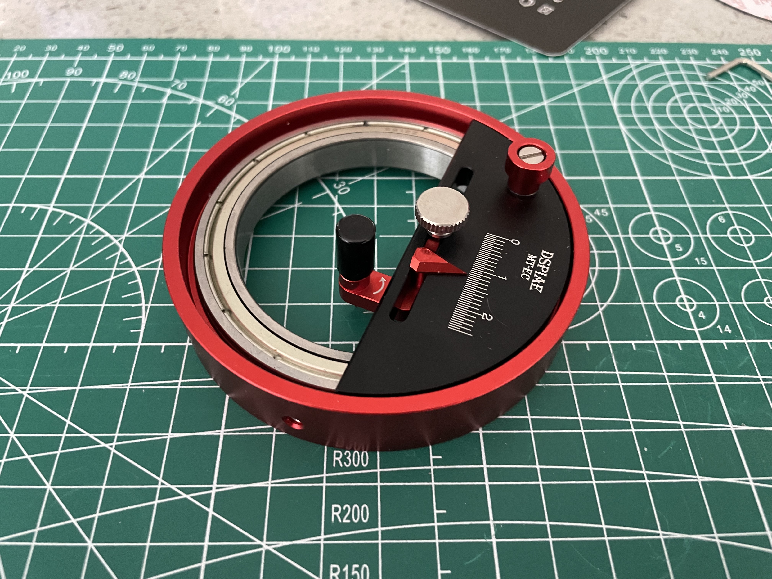
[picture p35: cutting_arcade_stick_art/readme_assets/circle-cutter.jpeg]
Circle cutting tool


When I first saw this tool, I thought it would be perfect. It has adjustable circle width, and you can also adjust the height to account for different paper thicknesses. In theory, this is very cool. 

In practice, it is not, at least not for this purpose. I think this tool could work just fine for thinner paper or for cutting out tape to mask pieces while you paint, but it was incredibly frustrating to use for me. 

The adjustable height would be a good feature if it stayed consistent, but my unit got loose after just one pass at trying to cut a circle. Even with dozens of practice cuts, I could not get consistent results. It was also even harder to use on the art itself because the ink made the paper more slippery, thus it was very prone to moving around. It's possible that a similar circle cutting tool with a different mechanism might work better, but I would definitely not recommend this one (at least for cutting art).

## Method 3: A rotating hobby knife

After I failed to get good results with the circle cutter, I thought, "Maybe my first approach was good, and I just need a different tool." So, I tried this:

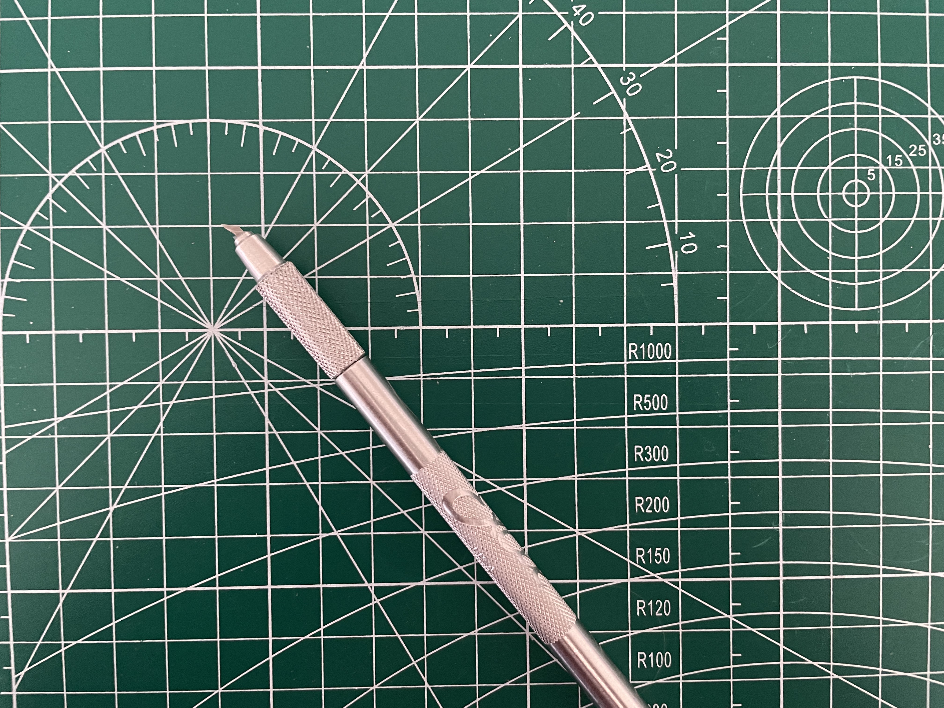
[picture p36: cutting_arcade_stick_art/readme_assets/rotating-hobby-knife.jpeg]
Rotating hobby knife


It is similar to a normal hobby knife, but the tip can spin 360 degrees. The idea is you can drag your hand along paper and get smooth curves. Here are the results:

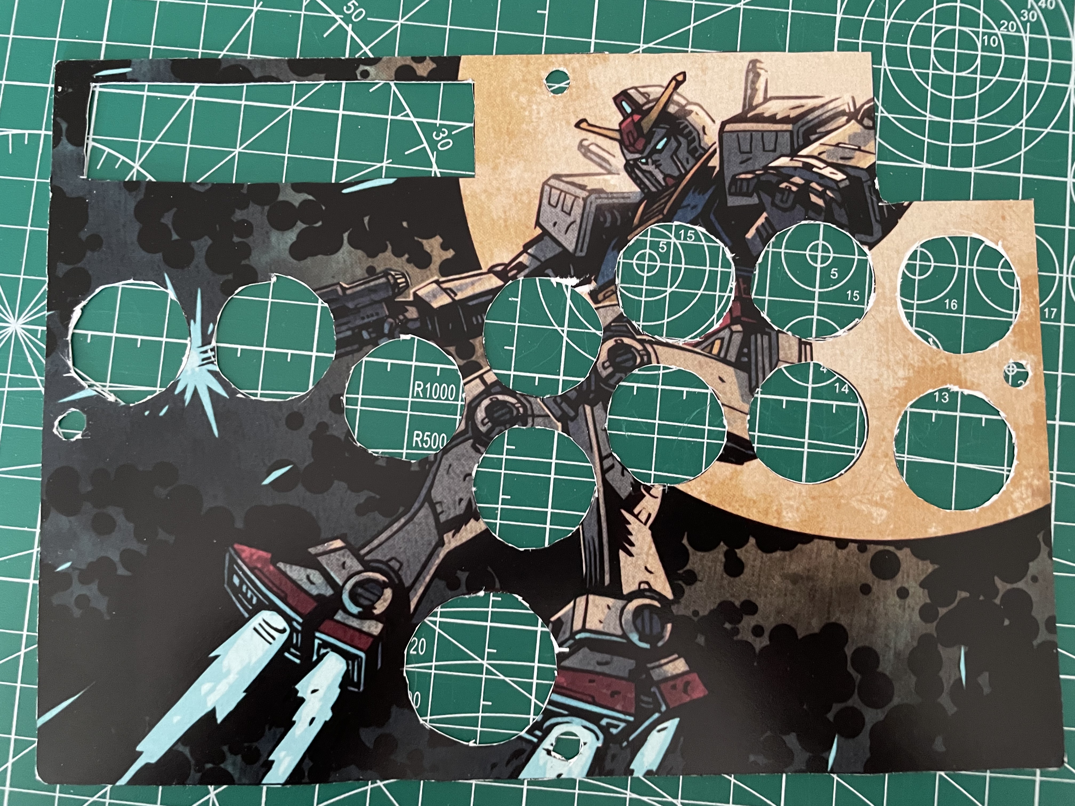
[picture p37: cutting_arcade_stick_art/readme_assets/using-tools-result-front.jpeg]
Front

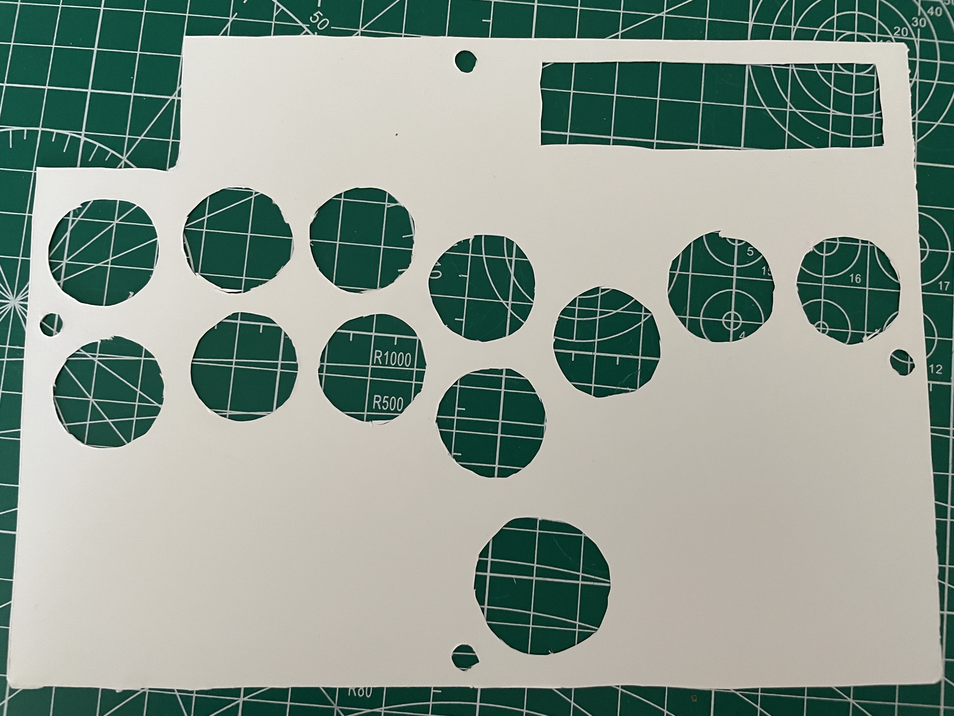
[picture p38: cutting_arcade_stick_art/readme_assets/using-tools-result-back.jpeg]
Back


This worked... okay. I got a couple of really good circles, but it was hard to stay consistent. The first tip I got with the knife broke immediately. Fine, I got some extra tips just in case. The second tip held up better, but I got the sense it was not meant to handle thick paper very well. 

The blade was sharp, but not really *that* sharp. I often felt like I was partially ripping the paper while I cut it, and I think the quality of the cuts shows that. I tried both freehand and using the acrylic plate as a guide on top of the art. I don't think either approach made a huge difference. Using the plate seems like it would help, but I got caught on the sides a lot. I think with a lot of patience and maybe a different paper thickness, this could give you good results, but it wasn't doing it for me.

## Method 4: A hole punch tool

Finally, we arrive at my real recommendation: a hole punch. But this is not the hole punch you may be used to. It looks like this:

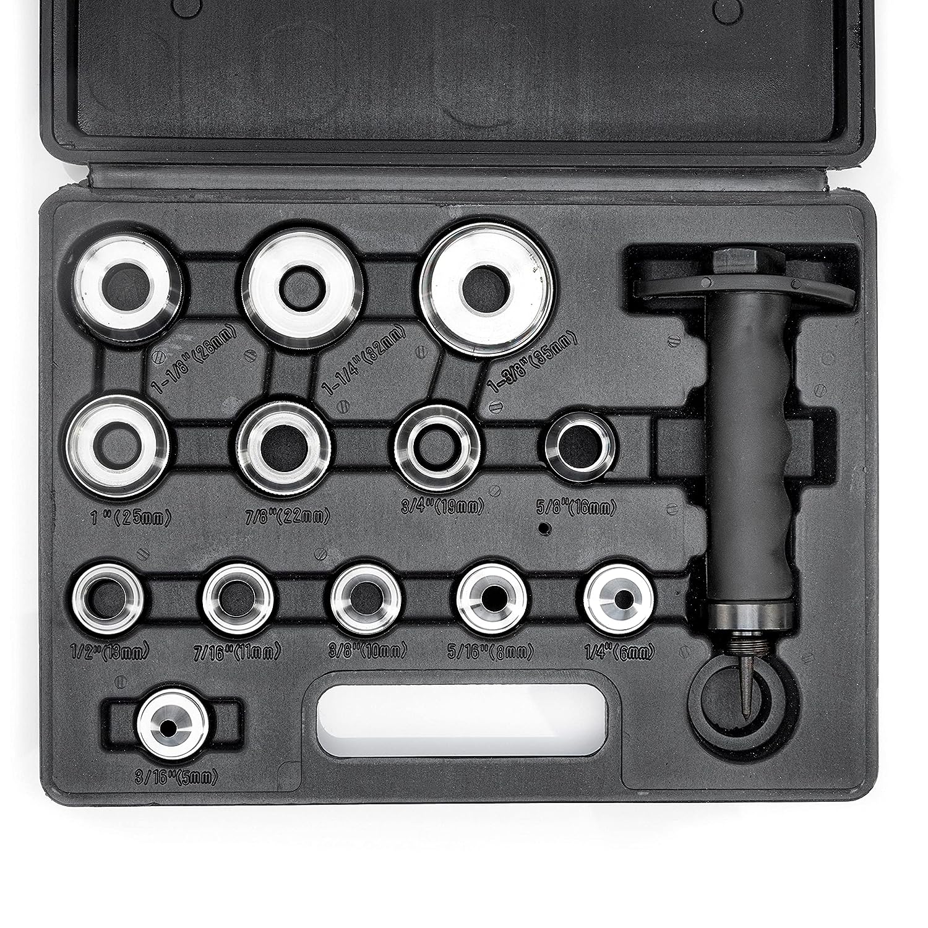
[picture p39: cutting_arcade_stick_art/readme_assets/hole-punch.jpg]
Hole Punch Tool


This is the tool I used specifically: [NEIKO 02604A Hole Punch Set](https://www.amazon.com/dp/B09YYWYNJ4). You line it up and then take a hammer and bang the top of it to cut. The concept is very similar to a normal hole punch, but more flexible with different sizes and no restriction on the depth of the thing you're cutting. 

Here are the results:

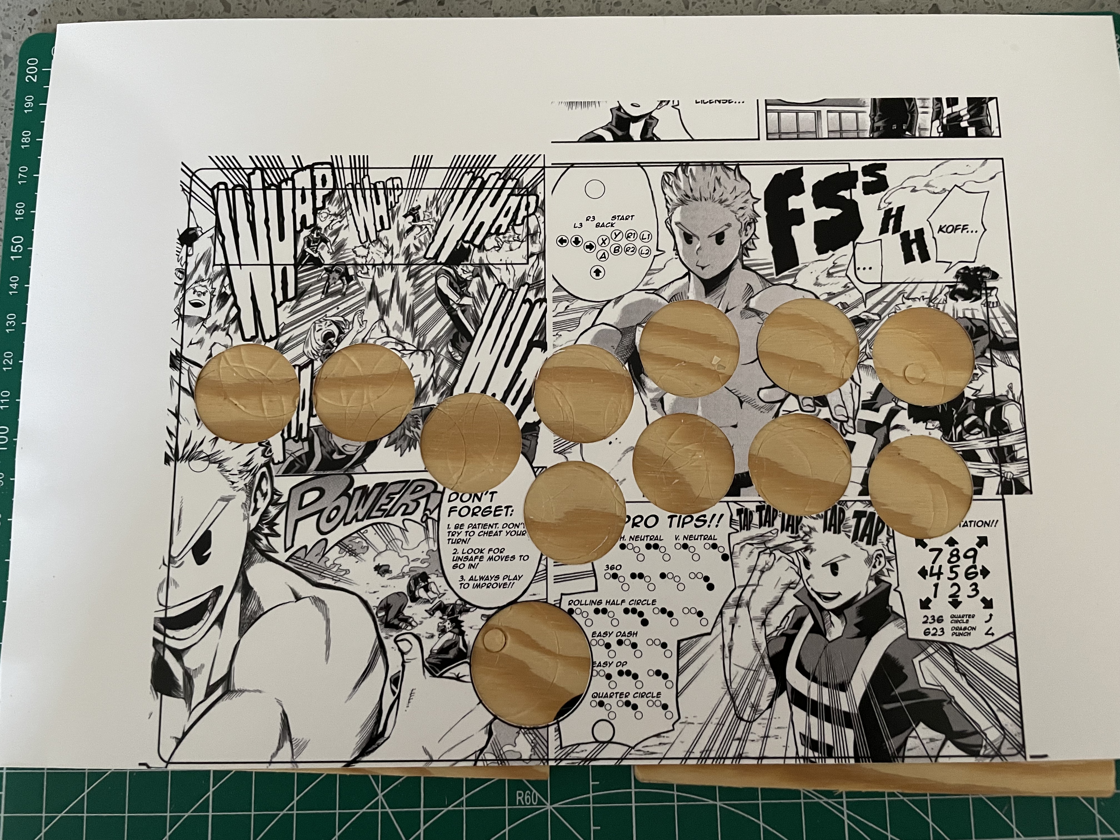
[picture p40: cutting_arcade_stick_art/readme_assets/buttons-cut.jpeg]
Mirio

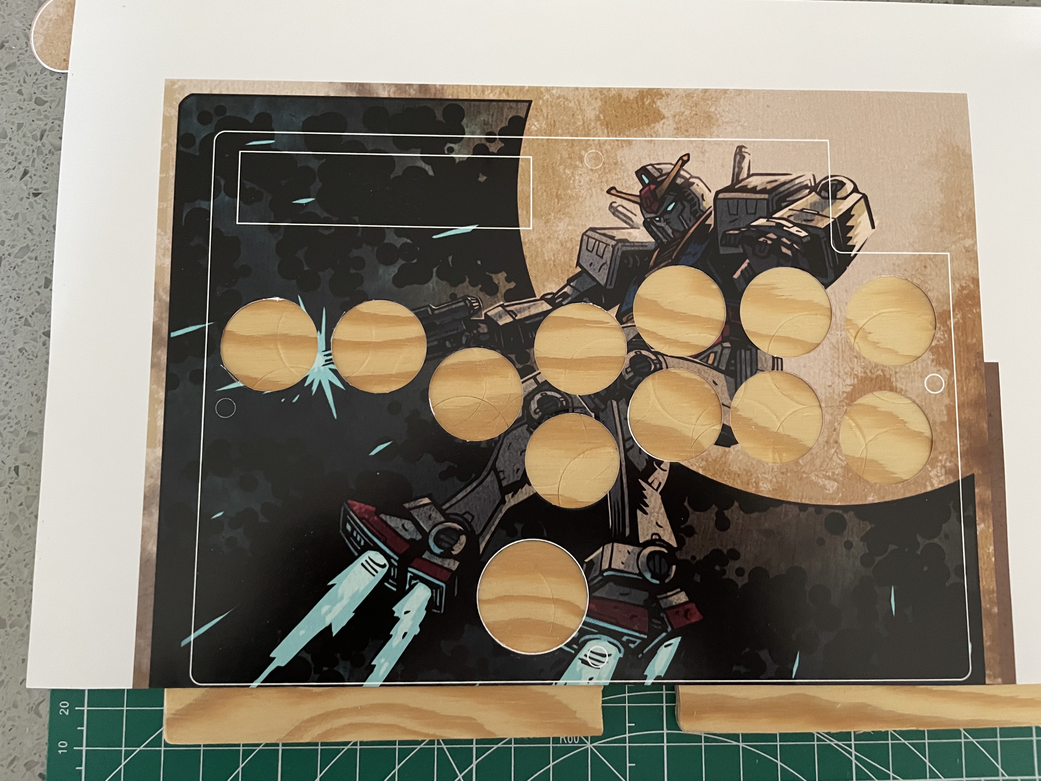
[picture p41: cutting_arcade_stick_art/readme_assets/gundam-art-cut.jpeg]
Gundam


Much, much better than anything up to this point. They're not quite perfect (I could have centered some of the holes a bit better, for example), but they look nice even from a close viewing distance, and you have to really inspect the controller to notice the issues. 

Here are some tips on using this tool:

### Use something relatively hard behind what you're cutting
The first time I tried this tool, I used it against cardboard. I think that might have worked eventually, but it absorbed a lot of the force. Instead, try some wood or something along those lines. 

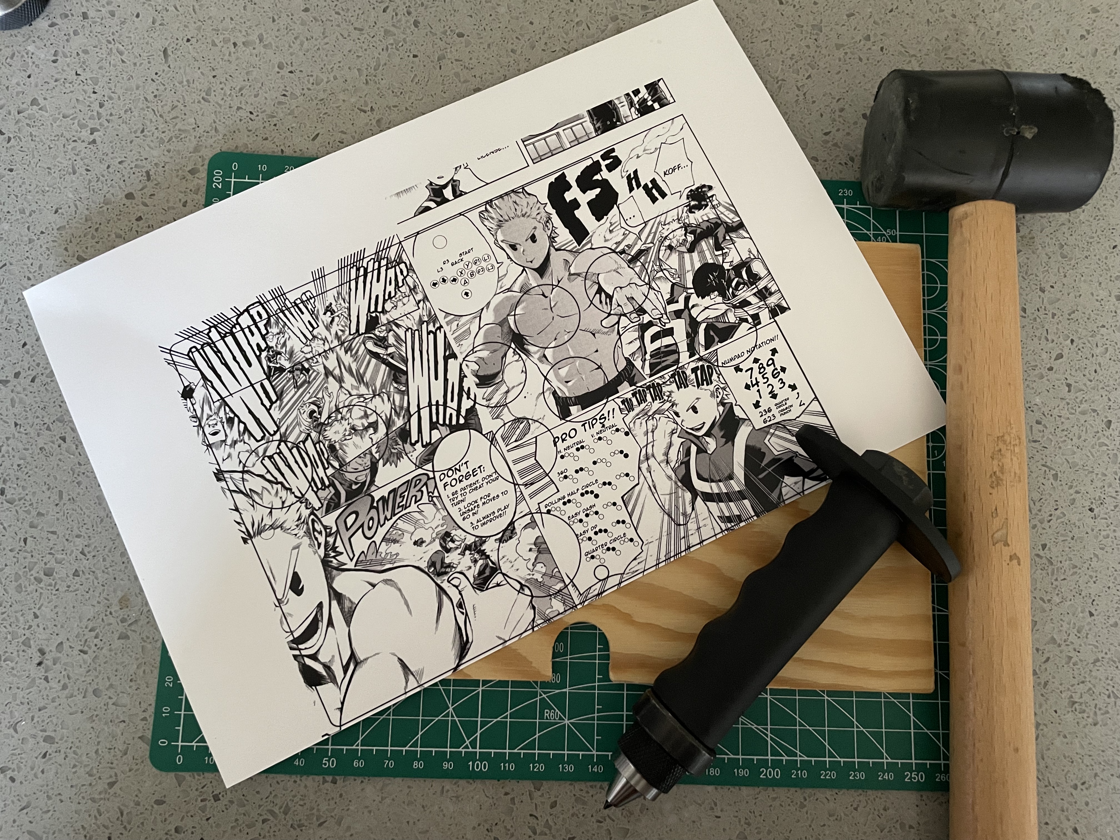
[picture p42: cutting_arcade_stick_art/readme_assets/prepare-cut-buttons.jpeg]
Preparing to hammer


With a really solid strike or two, you can get a nice, clean circle. 

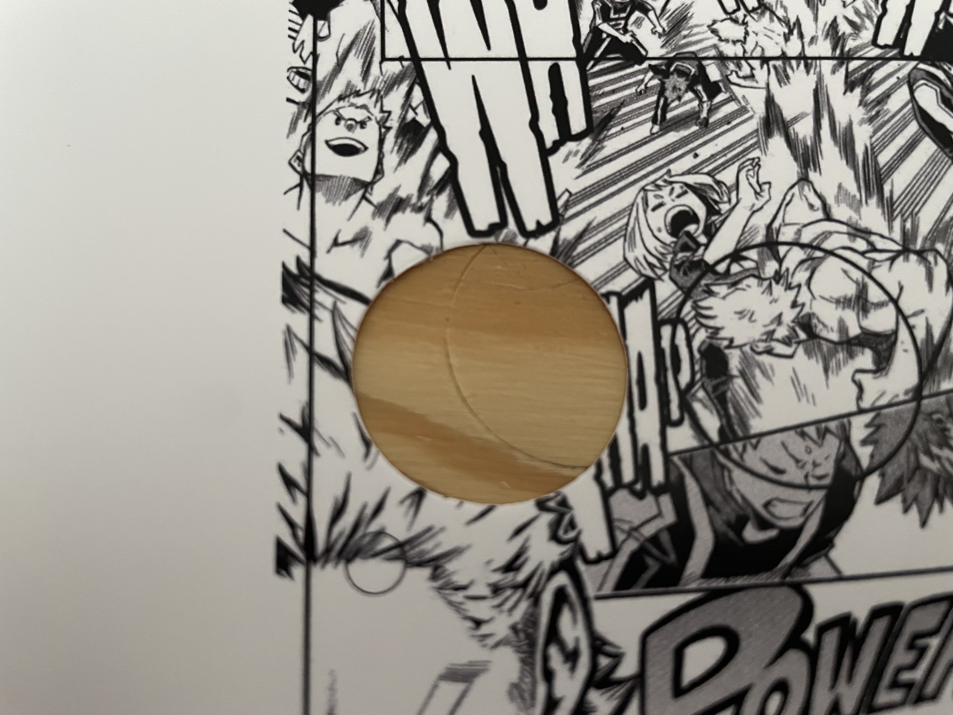
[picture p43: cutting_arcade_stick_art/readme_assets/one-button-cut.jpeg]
Button cut out


I used the underside of a lid to a box that I store my soldering supplied in, but a piece of scrap wood is better. This will make some marks in the wood. 

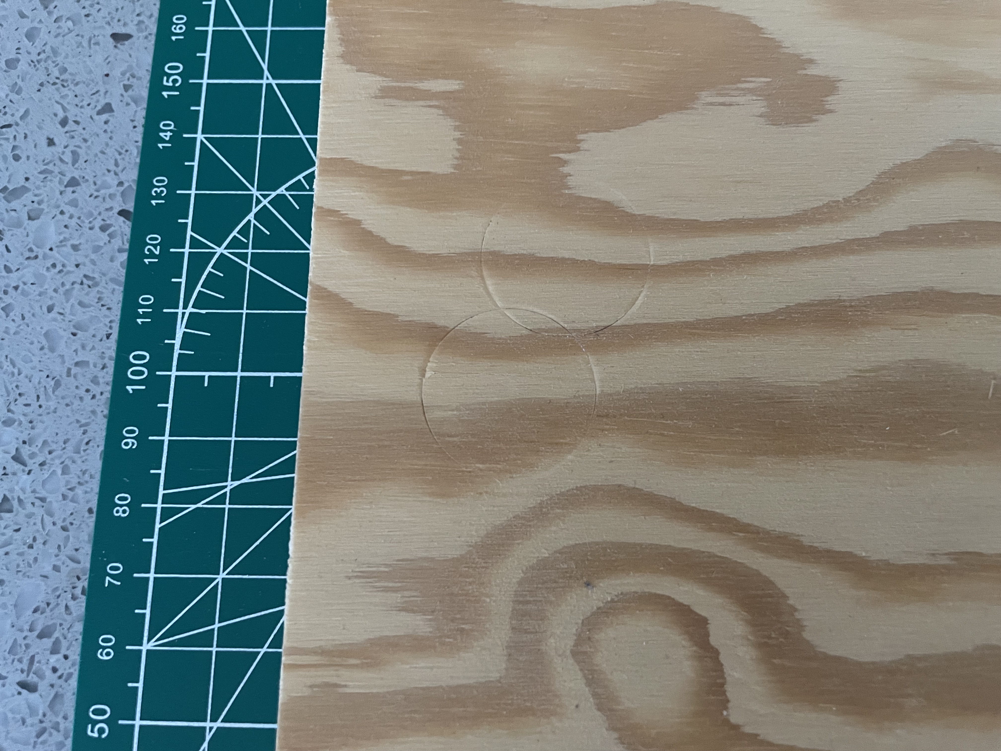
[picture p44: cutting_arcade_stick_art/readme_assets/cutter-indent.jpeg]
An indent in the wood behind the art


Seriously, especially if you also use this tool to cut the smaller holes, it will be noticeable. 

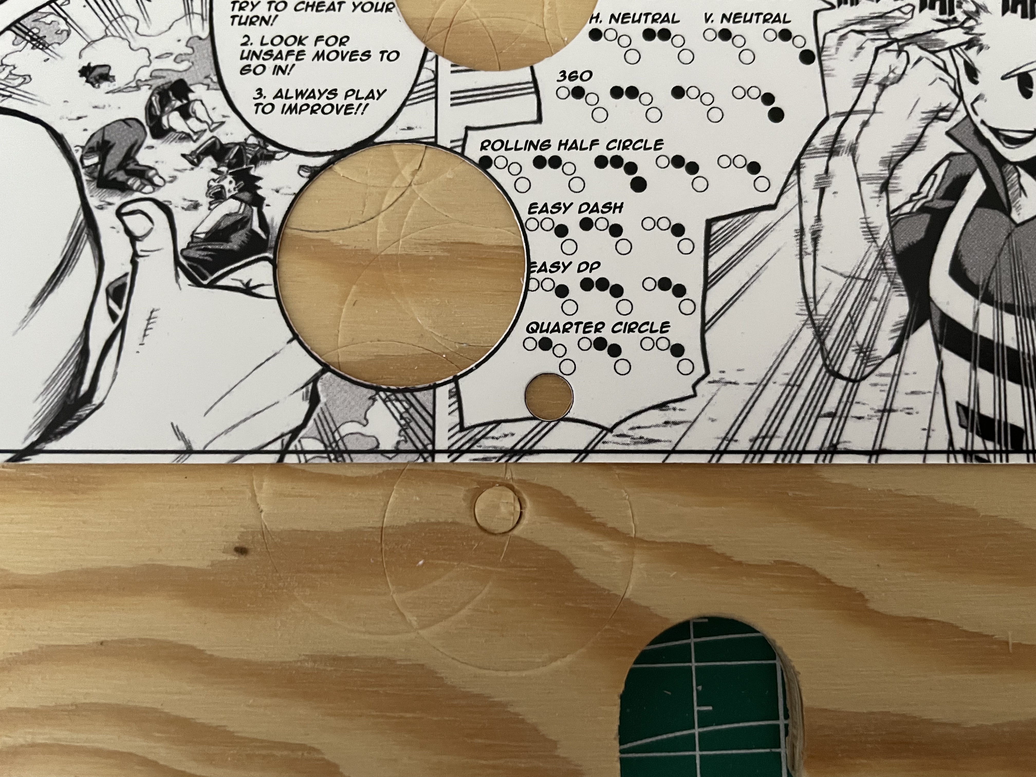
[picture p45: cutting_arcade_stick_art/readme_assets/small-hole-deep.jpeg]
A deep indent


### Make sure the punch is entirely in contact with the paper

This was the thing I struggled with the most using this tool. You have to make sure the tool is flat against the artwork and you strike it nice and vertically. 

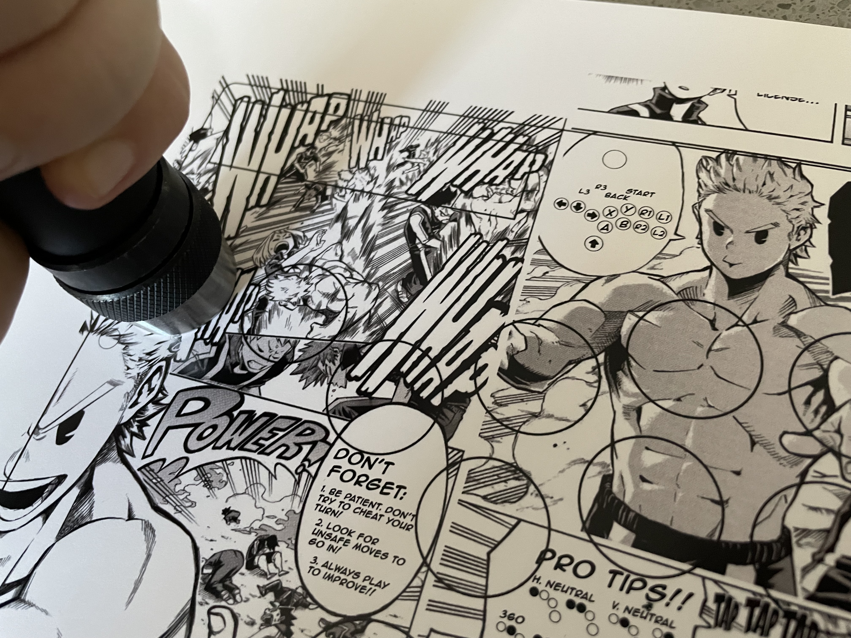
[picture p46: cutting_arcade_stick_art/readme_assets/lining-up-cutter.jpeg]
Aligning the cutter


I experimented with shifting the pressure around from one side to the other, but I got the best results from a solid vertical hit. I usually hammered each hole twice. Once I got used to it, most of them popped out perfectly. A few were nearly fully cut, which is easy to fix by hand. 

### You can use a hobby knife to fix incomplete cuts
Speaking of fixing cuts, if the punch didn't quite make a full circle, you have a judgement call to make: try the punch again or use a hobby knife. 
 
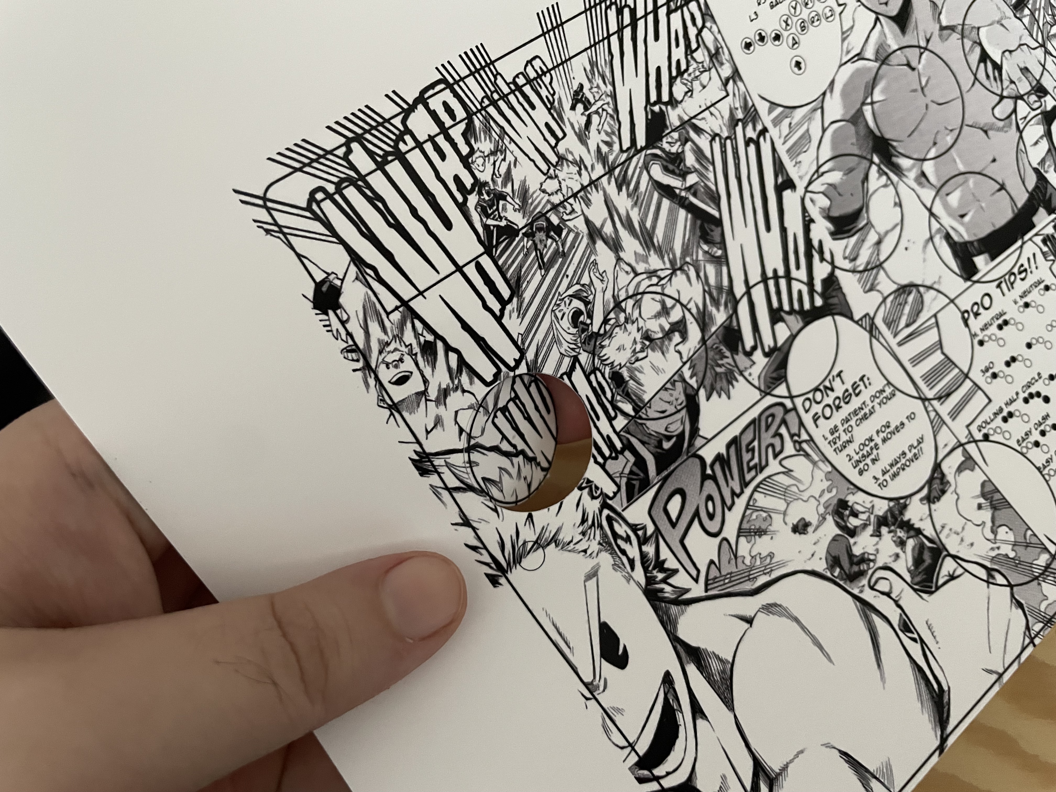
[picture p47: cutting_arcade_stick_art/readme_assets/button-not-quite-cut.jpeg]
Button about three-quarters cut


If you have a case like the above where the hole is two-thirds to three-quarters cut (or less), I'd try the hole punch again. The risk to this is if you're not aligned with your last hole, it can end up looking weird or creating small slivers of paper along the edge of holes to trim off. 

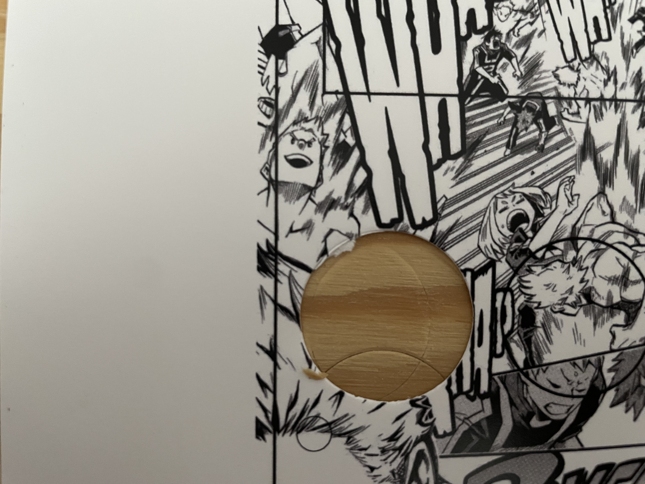
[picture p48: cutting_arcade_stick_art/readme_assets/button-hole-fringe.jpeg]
Button hole cut but with some paper fringe


You may also run into holes with a little bit of excess paper or that are nearly fully cut. In this case, I preferred to use a hobby knife to finish the job. You can use very light pressure, which keeps the knife controllable. If a button is almost cut but not quite, I like to finish the cut from the back of the art.

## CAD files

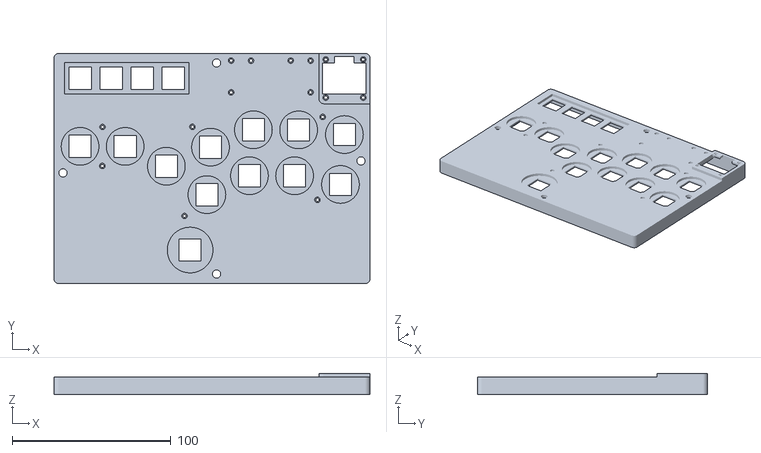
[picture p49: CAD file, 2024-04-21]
EXPress_Body.stl
199.0 x 145.0 x 13.3

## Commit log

2024-04-21 EXPress initial commit
    [EXPress_Body.stl]
2024-04-21 Correcting switch type in readme
